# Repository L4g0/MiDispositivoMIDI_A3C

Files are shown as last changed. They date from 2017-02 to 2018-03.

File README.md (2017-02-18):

# BanaNut Electronics
Hi! We are BanaNut Electronics and we develop software and hardware for Arduino with educational purposes. Feel free to visit us in out social networks:
* Instagram: https://www.instagram.com/bananutelectronics
* Twitter: https://twitter.com/bn_electronics
* Facebook: https://www.facebook.com/bananutelectronics
* Tindie: https://www.tindie.com

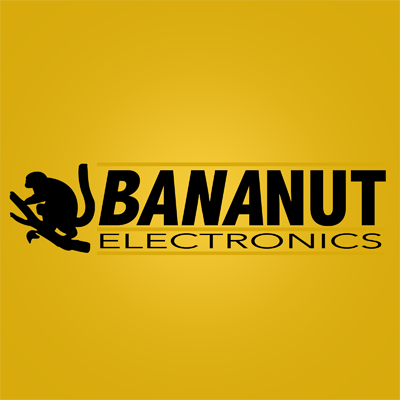
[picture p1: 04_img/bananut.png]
BN_PIC


# MiDispositivoMIDI_A3C
We are proud to present the MiDispositivoMIDI revA3C ([what is that?](https://github.com/bananutelectronics/MiDispositivoMIDI_A3C/wiki), which is the latest version we have out in the market. You can buy it in our webpage or in tindie. In this repository you will find documentation about the controller and code. If you know how to code and you want to colaborate with the project, feel free to do it. If you don't, here you will find a bunch of codes that you just will need to upload to your controller, simple as that.
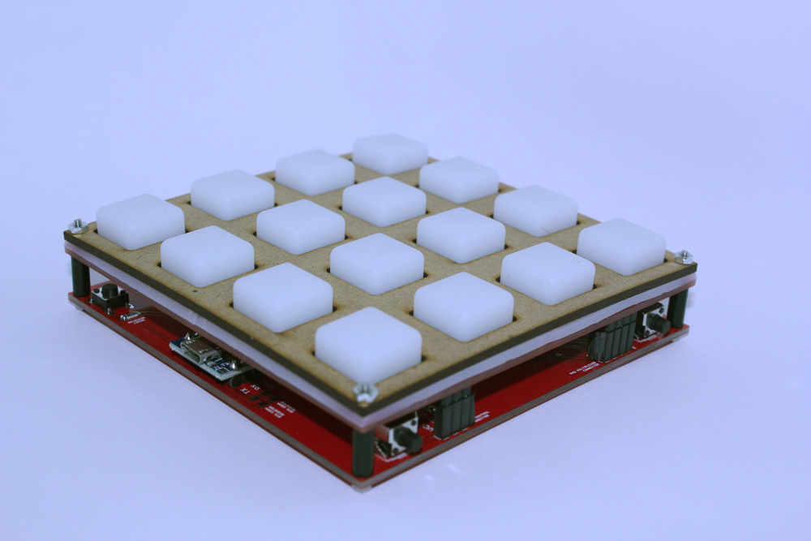
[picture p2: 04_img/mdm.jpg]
MDM_V3_1

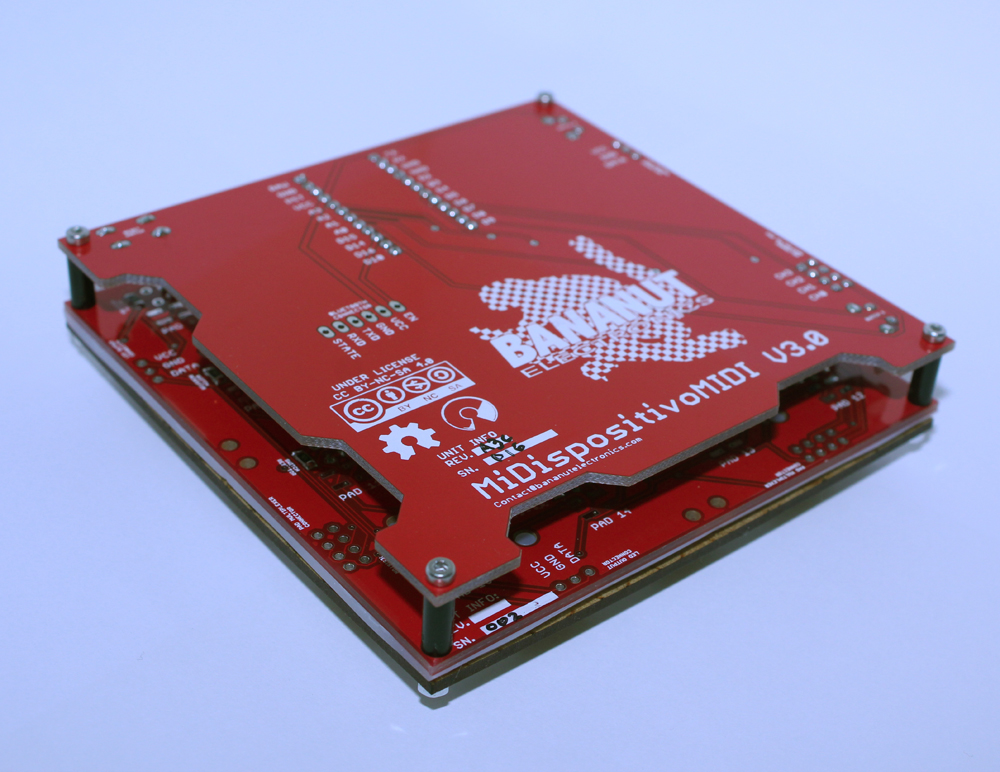
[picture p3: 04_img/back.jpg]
MDM_V3_2


# Important
You will need the following libraries to make the code work: MIDI USB and Adafruit NeoPixel
* https://github.com/arduino-libraries/MIDIUSB
* https://github.com/adafruit/Adafruit_NeoPixel

We also recommend using the Arduino Sketch to make the programming. Remember to select "Arduino Leonardo" as target board.

# Media
* https://www.youtube.com/watch?v=3QnzLwpbpRE&t
* https://www.youtube.com/watch?v=8WFfShg-0Dk
* https://www.youtube.com/watch?v=2y8fhmTmedI
* https://www.youtube.com/watch?v=TsuVpFoLFyI

# General information
* MiDispositivoMIDI is the latest version of our controller.
* It can act as any other MIDI device. There is no need to convert from serial to MIDI.
* Have 16 pad buttons in a 4x4 matrix.
* Have 2 lateral buttons.
* Have RGB leds with 256 levels of intensity of each color.
* Micro USB conection.
* Dimensions of 10x10 cm.

# Documentation
Check the wiki section for further information.

# Hardware License
<br /><span xmlns:dct="http://purl.org/dc/terms/" property="dct:title">MiDispositivoMIDI</span> by <a xmlns:cc="http://creativecommons.org/ns#" href="www.bananutelectronics.com" property="cc:attributionName" rel="cc:attributionURL">Alvaro Lopez & Pablo de Miguel Morales</a> is licensed under a <a rel="license" href="http://creativecommons.org/licenses/by-nc-sa/4.0/">Creative Commons Attribution-NonCommercial-ShareAlike 4.0 International License</a>.<br />

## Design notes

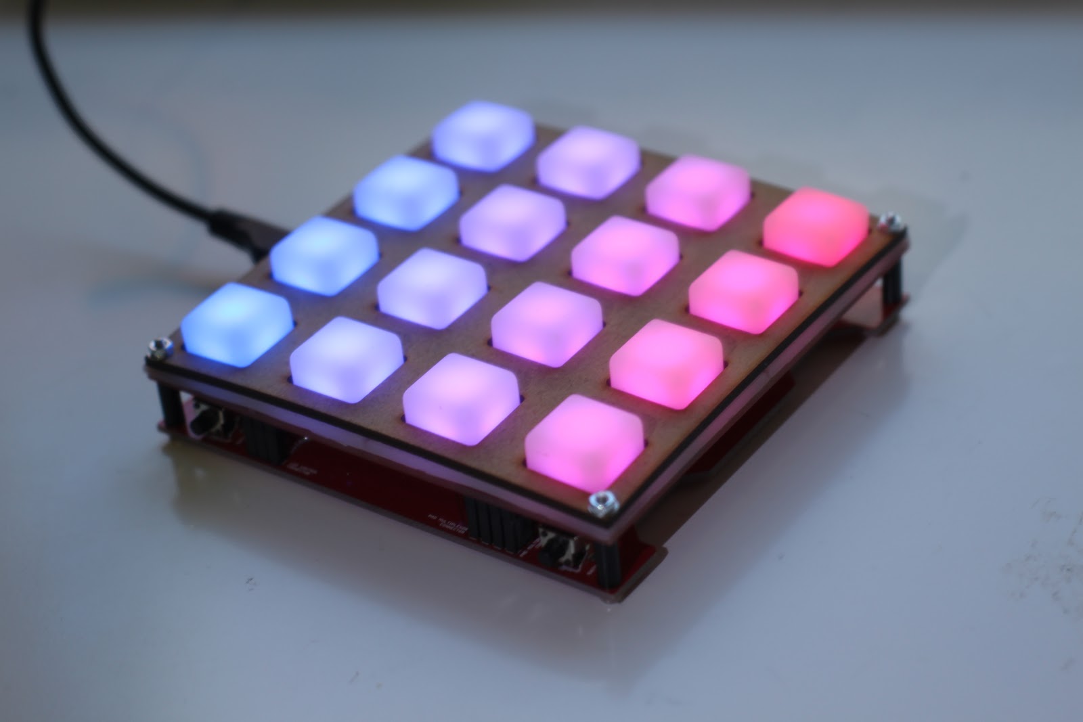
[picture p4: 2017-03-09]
04_img/MDM_V3_INTRO_Device0.JPG

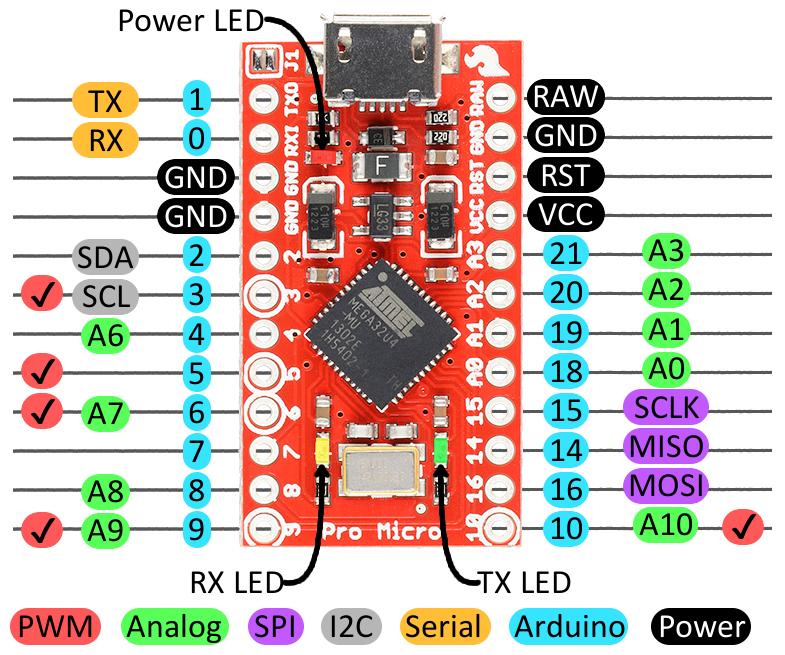
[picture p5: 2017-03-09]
04_img/MDM_V3_HW_ArduinoPinOut.png

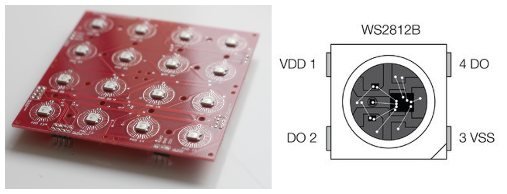
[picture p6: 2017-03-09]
04_img/MDM_V3_HW_WS2812B.PNG

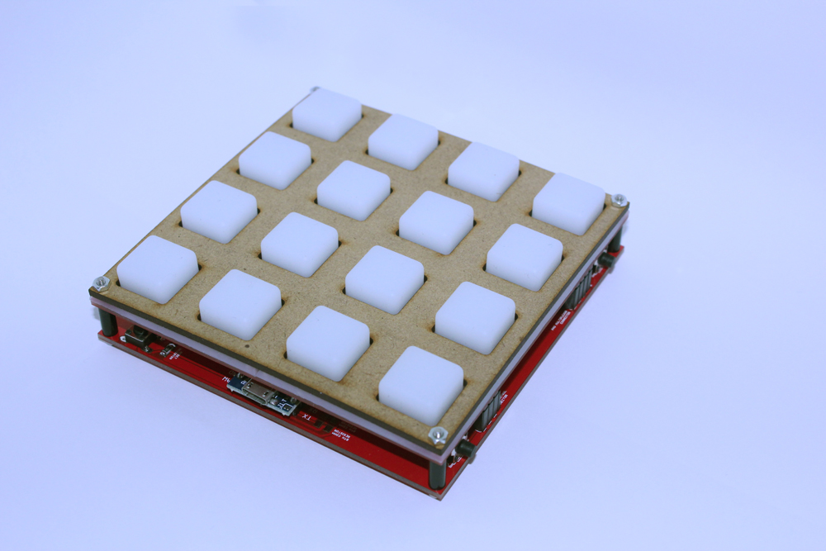
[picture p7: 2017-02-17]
04_img/top.jpg

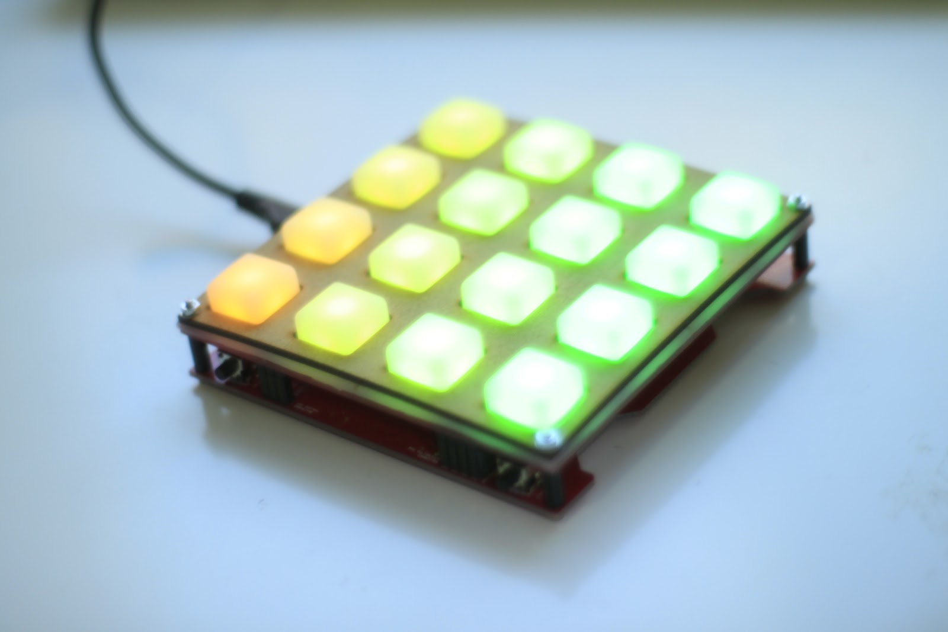
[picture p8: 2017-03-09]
04_img/MDM_V3_INTRO_Device1.JPG

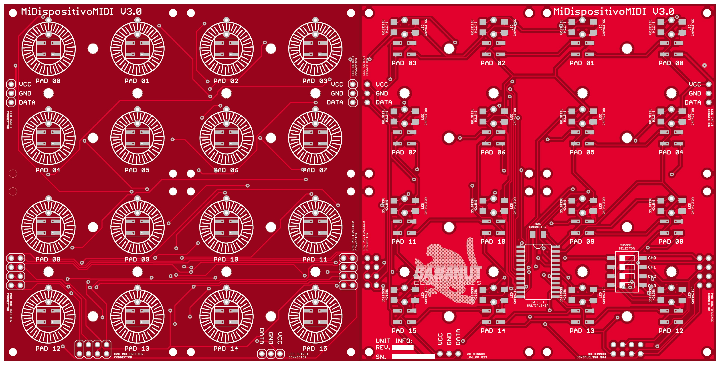
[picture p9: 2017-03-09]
04_img/MDM_V3_HW_LEDPAD_Layer.PNG

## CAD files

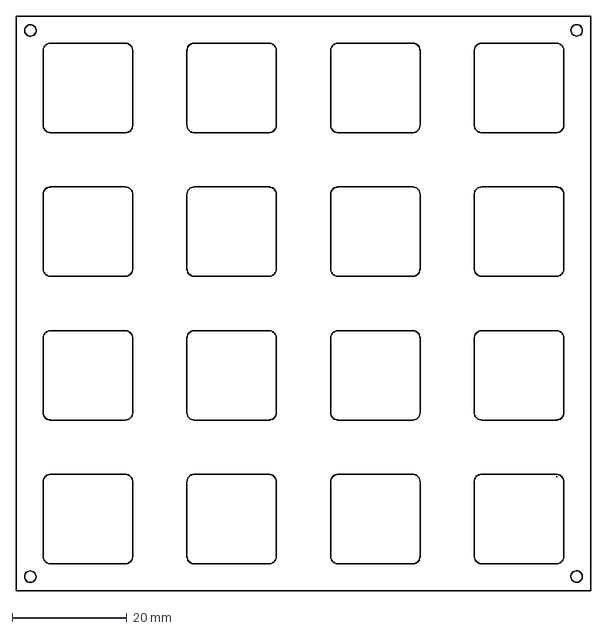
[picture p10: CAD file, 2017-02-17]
02_hw/MDM_V3_Cover.dxf
100.0 x 100.0 mm

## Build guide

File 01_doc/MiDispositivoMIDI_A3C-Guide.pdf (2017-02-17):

Tabla de Contenido
1. Introducción
1.1. ¿Que es MiDispositivoMIDI?
1.2. ¿Que es este documento?
1.3. Desarrollo
2. Protocolo MIDI
2.1 Introducción
2.2 Tipos de mensajes
3. Hardware
3.1. Elementos
3.2. Niveles PCB
3.2.1. MDM_ControlBoard
3.2.2. MDM_LEDPad
3.3. Elementos
3.3.1. LED RGB WS2812B
3.3.2. Multiplexor 74HC4067
3.3.3. Arduino Leonardo Micro Pro
4. Software
4.1 Introducción a la programación 4.1.1 Código
4.1.2 Lenguajes de programación 4.1.3 Entornos de desarrollo 4.1.4 Estructuras de control
4.2 Instalación IDE Arduino
4.3 Funcionamiento IDE Arduino
4.3.1 Fundamentos Arduino
4.3.2 Carga y Compilación de Sketches 4.4 Ejercicios
4.4.1 Ejercicio 1
4.4.2 Ejercicio 2
4.4.3 Ejercicio 3
4.4.4 Ejercicio 4
4.4.5 Ejercicio 5
5. Secuenciadores
5.1 Configuración Ableton
6. Conclusión
6.1 Extensión
6.3 Foro web
6.4 FAQ
7. Inventario de vídeos
8. Inventario código

MiDispositivoMIDI V3.0. User Guide Page 0

# 1. Introducción

## 1.1. ¿Que es MiDispositivoMIDI?

MiDispositivoMIDI es un controlador MIDI Open Source basado en Arduino. Puede ser usado con cualquier programa de audio como Ableton o Logic y dispone de las siguientes características:
- 16 botones tipo PAD ON/OFF, dispuestos en una matriz de 4x4.
- 16 LED RGB, situados debajo de cada botón.
- 2 botones laterales configurables.
- Conexión USB con cable MicroUSB.
- Dimensiones de 10x10 cm.

El controlador viene programado por defecto y se comercializa montado y listo para ser utilizado. También se le pueden cargar los códigos disponibles en nuestro repositorio de GitHub o programar a medida.

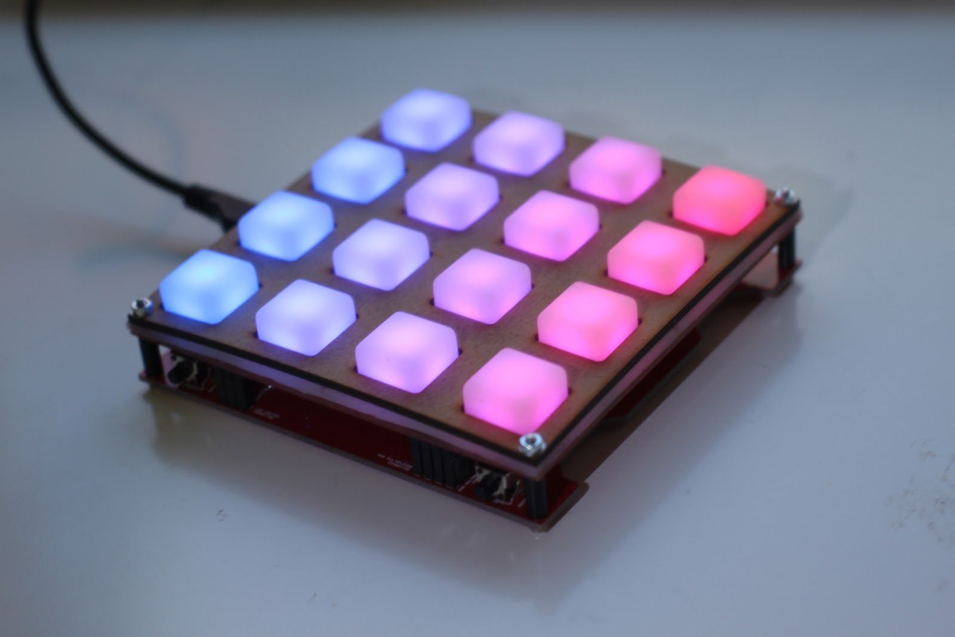
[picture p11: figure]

Figura 1. MiDispositivoMIDI en funcionamiento (1/2).

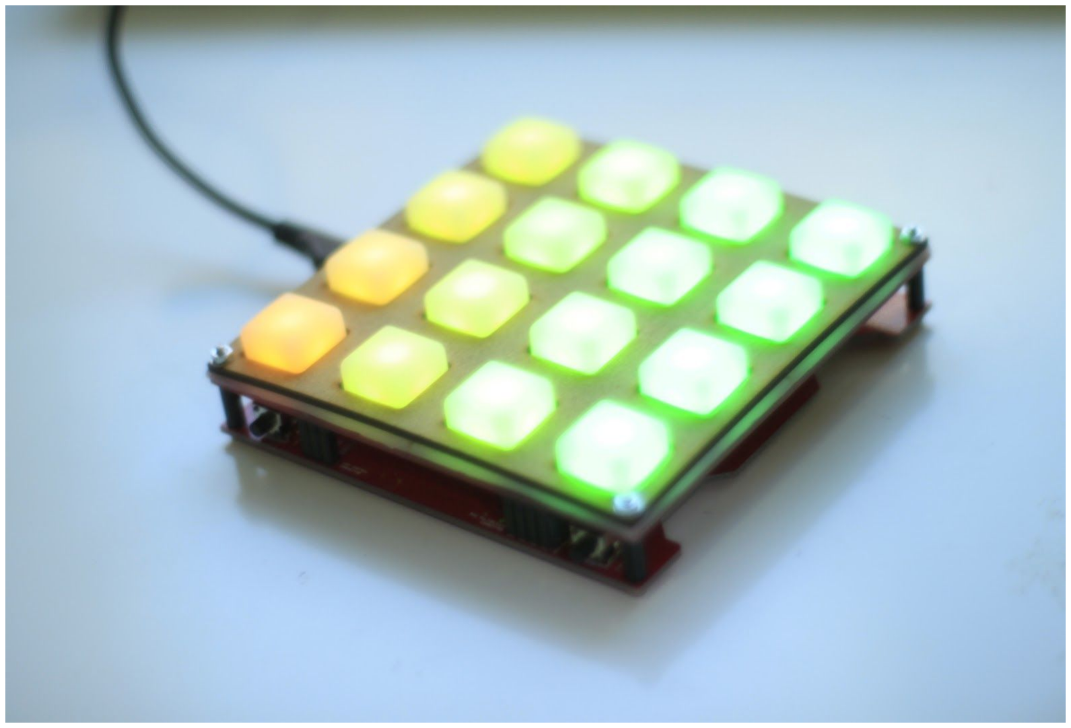
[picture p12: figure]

Figura 2. MiDispositivoMIDI en funcionamiento (2/2).

## 1.2. ¿Que es este documento?

Esta guía pretende orientar a los usuarios del controlador MiDispositivoMIDI Rev A3C. Se cubren aspectos desde lo más general (uso, configuración, componentes,...) hasta lo más avanzado (programación, esquemáticos, circuitos). Además del presente documento, se recomienda consultar:
- Vídeos de youtube: En estos vídeos se explican ciertos apartados de la guía, de manera más visual. Enlace. (https://www.youtube.com/channel/UCHQbpOPa1lVauoBouRJ16Iw)
- Repositorio: En dicho repositorio (https://github.com/bananutelectronics/MiDispositivoMIDI_A3C) de GitHub se pueden encontrar diversos códigos que puedes cargar en el controlador, sin tener conocimientos de ningún tipo. Para cargar códigos, ver el vídeo “Instalación”. (https://www.youtube.com/channel/UCHQbpOPa1lVauoBouRJ16Iw)

## 1.3. Desarrollo

El controlador MiDispositivoMIDI tiene sus orígenes en la Universidad Politécnica de Madrid (UPM), donde dos alumnos de Ingeniería de Telecomunicación, decidieron empezar con un controlador MIDI basado en Arduino.
Su primera versión, se basaba en Arduino UNO, empleaba registros de desplazamiento para la iluminación de los LEDs y enviaba mensajes empleando el puerto serial. De dicha versión se hicieron 40 unidades, y se impartió el primer curso, allá por el año 2013.
Tras varias mejoras y cambios de firmware en el Arduino, se llegó a la versión 2.0 del controlador. Las carcasas eran de madera, y la comunicación con el ordenador ya se establecía a través de MIDI. Se hicieron también 40 unidades, y se impartió un curso con muy buena acogida.

Tras un tiempo parados, pero habiendo escuchado todas las mejoras propuestas por nuestros compañeros, decidimos lanzar la tercera versión de MiDispositivoMIDI. Se trata de un controlador mucho más fino, más ligero, con un Arduino más potente, LEDs que permiten generar miles de colores y fácilmente ampliable. Hemos fabricado una tirada grande de esta tercera versión, y ¡estamos deseando dártela!

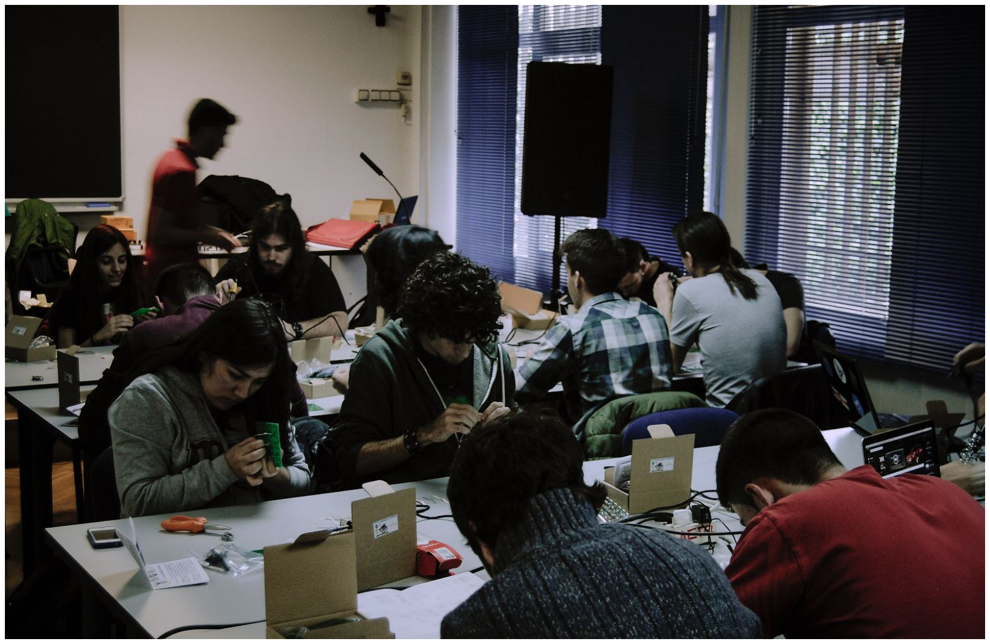
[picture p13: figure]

Figura 3. Asistentes de la primera edición de MiDispositivoMIDI.

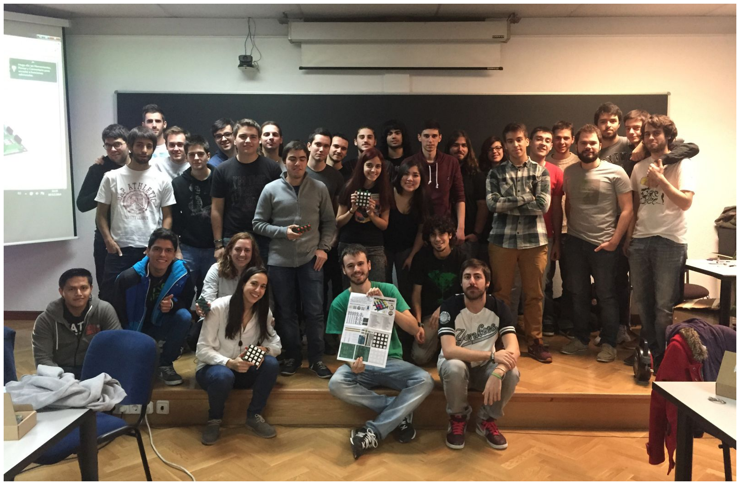
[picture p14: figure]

Figura 4. Asistentes de la segunda edición de MiDispositivoMIDI.

# 2. Protocolo MIDI

## 2.1 Introducción

El protocolo MIDI (Musical Instruments Digital Interface) es un lenguaje que utilizan actualmente muchos instrumentos musicales para comunicarse entre ellos y con un ordenador. Su uso les permite enviar y recibir mensaje además de sincronizarse. Se trata de un protocolo con mucha historia, y data de la década de los 80s. Aún así, se sigue usando hoy en día en gran cantidad de teclados, controladores, cajas de ritmo e incluso para controlar luces.

Por ejemplo, el teclado que mostramos a continuación se puede conectar al ordenador con un cable USB y cuando pulsemos una tecla, enviará un mensaje MIDI al ordenador a través del cable. Evidentemente no va a ser el mismo mensaje si pulsamos la tecla muy fuerte o suave, o si pulsamos una tecla u otra. A continuación lo explicaremos.

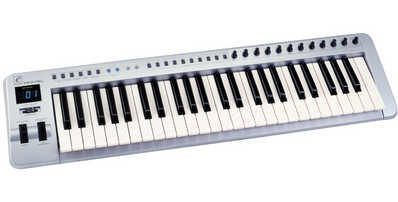
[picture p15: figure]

Figura 5. Ejemplo de controlador MIDI. Teclado controlador.

## 2.2 Tipos de mensajes

Antes de nada vamos a recordar que es un bit y un byte. Un bit es la unidad mínima de información digital, es decir un 0 o un 1. Un byte es un conjunto de 8 bits. Cada mensaje MIDI tiene 3 bytes, es decir 24 bits. En función del valor que tenga, el mensaje significará una cosa u otra. A continuación mostramos los 3 paquetes de 1 byte que contiene cada mensaje MIDI. El primero corresponde al byte de estado, y lleva la información relativa al estado y el canal. El estado hace referencia al tipo de mensaje: nota activada, nota desactivada, bend, cambio de programa u otros más. El canal puede tomar valores de 0 a 15, y permite separar diferentes flujos de mensajes.

BYTE 1 (Status Byte)

Estado | Canal
X | X | X | X | X | X | X | X
El segundo y tercer byte, llevan información que variará en función del estado. Para el caso de un estado noteOn, el BYTE 2 indicará la nota y el BYTE 3 indicará la intensidad de la nota.
BYTE 2 (Data Byte 1)
X | X | X | X | X | X | X | X

BYTE 3 (Data Byte 2)

X | X | X | X | X | X | X | X

Particularizando para el ejemplo de un mensaje de nota activada noteOn, vamos a ver los bits que se enviarán para un caso concreto.

Ejemplo noteOn

Nota | DO
Octava | 3
Intensidad | Máxima
Canal | 0

Por un lado, la tercera octava de DO se corresponde con el valor MIDI 48. La intensidad máxima se corresponde con el valor 127, ya que en MIDI las intensidades varían desde 0 a 127, siendo 0 la menor. Sabiendo que 48 en binario es 0110000, 127 es 1111111, el código de noteOn es 1001 y 0 en binario es 0000, tenemos lo siguiente:

noteOn | Canal | | Nota | | Intensidad
1 | 0 | 0 | 1 | 0 | 0 | 0 | 0 | 0 | 0 | 1 | 1 | 0 | 0 | 0 | 0 | 0 | 1 | 1 | 1 | 1 | 1 | 1 | 1

Como podemos ver, el bit 9 y el 17 se indican en color rojo. Esto es debido a que estos bits van a ir siempre a 0, sin importar el mensaje enviado. Para otros mensajes, la estructura es similar.

EJERCICIO PROPUESTO (INDICADOR NÚMERO)

Se propone escribir el mensaje MIDI completo en binario que se enviaría al pulsar la nota

LA de la tercera octava, con una intensidad de 90.

# 3. Hardware

## 3.1. Elementos

MiDispositivoMIDI V3 está conformado por diversos elementos que componen tanto su estructura mecánica como su estructura electrónica. En las siguientes secciones se recogen y analizan distintos aspectos del circuito para que sean comprendidos tanto por iniciados como por usuarios más avanzados de la electrónica.

Los elementos que componen MiDispositivoMIDI V3 son:

QUANTITY. | ITEM

01 Silicone Pad 4x4 10x10cm

01 Wooden CNC Laser Cut MiDispositivoMIDI V3 Cover

01 PCB MDM_V3_ControlBoard

01 PCB MDM_V3_LedPad

01 Arduino Leonardo Micro Pro

16 WS2812B RGB Addressable LED

18 Ceramic Capacitor SMD 1206 10uF

19 Resistor SMD 1206 10kOhm

01 Resistor SMD 1206 47Ohm

02 Angled Tactile Switch

01 Tactile Switch

01 IC 74HC4067 16to1 Multiplexer

01 DIP Switch 1x4 SMD

01 Male 2x4 Pin Row

01 Male 1x3 Pin Row

01 Female 2x4 Pin Row

01 Female 1x3 Pin Row

04 M2x20 Screw

04 M2 Black Plastic Screw Separator

04 M2 Washer

04 M2 Nut

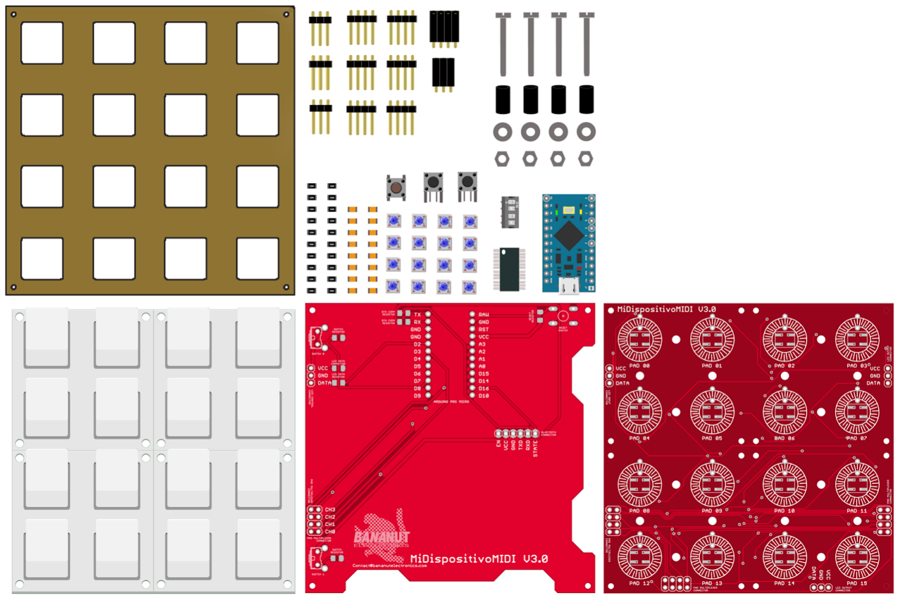
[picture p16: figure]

Figura 6. Componentes de MiDispositivoMIDI.

## 3.2. Niveles PCB

MiDispositivoMIDI V3 está conformado por 2 distintas PCBs. Una PCB (Printed Circuit Board) es una lámina de fibra con pistas conductoras metálicas sobre las que se sueldan los componentes de cualquier producto electrónico. Las PCBs se pueden encontrar en todos los dispositivos independientemente de su complejidad y función.

MiDispositivoMIDI hace uso de dos PCB conectadas a través de pines (sin cables) de modo que se trata de una conexión muy robusta.

### 3.2.1. MDM_ControlBoard

La placa de control (MDM_ControlBoard) contiene la unidad principal de procesado del dispositivo con el microcontrolador Arduino Leonardo así como los dos botones de control (Switch 0 y Switch 1) y un botón de Reset (Reset Switch). Dispone también de un pad en el que se puede soldar un módulo Bluetooth. Esta funcionalidad, sin embargo, no ha sido todavía implementada pero se anima a todo aquel que quiera intentarlo a experimentar con un MiDispositivoMIDI inalámbrico.

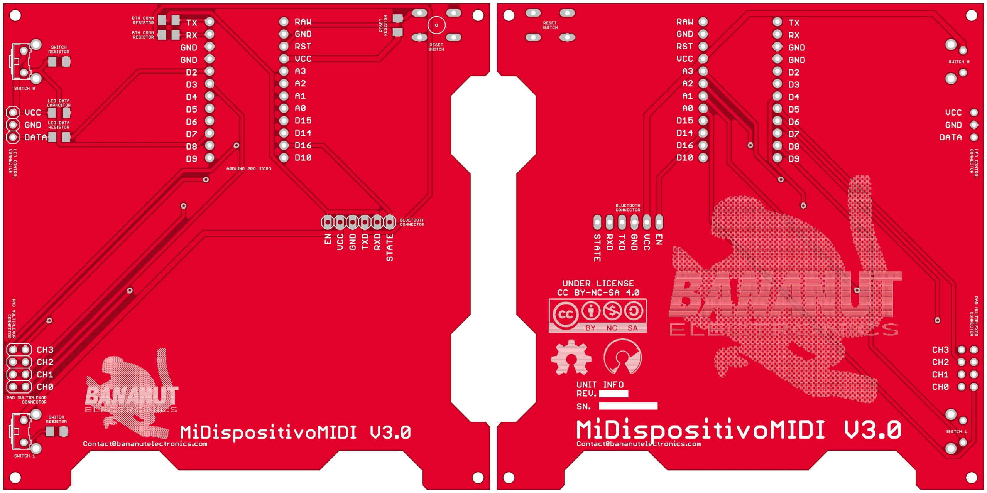
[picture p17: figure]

Figura 7. PCB inferior de MiDispositivoMIDI. A la izquierda se muestra la capa superior, a la derecha la inferior.

### 3.2.2. MDM_LEDPad

La placa del Pad Led 4x4 (MDM_LEDPad) conforma junto con el Pad de silicona la parte principal del dispositivo. Consiste en un Pad formado por 16 LEDs WS2812B dispuestos en una fila. El funcionamiento de estos LEDs se describe más adelante en este documento. Cuenta además con resistencias para los switchs y un multiplexor 74HC4067 que permite el control de todos los pads a través de solo 5 pines.
Una peculiaridad atractiva de MiDispositivoMIDI es la posibilidad de conectar hasta cuatro MDM_LEDPad con un solo MDM_ControlBoard. Esto abre la posibilidad a montar un MiDispositivoMIDI de 8x8 o 4x16 Pads.

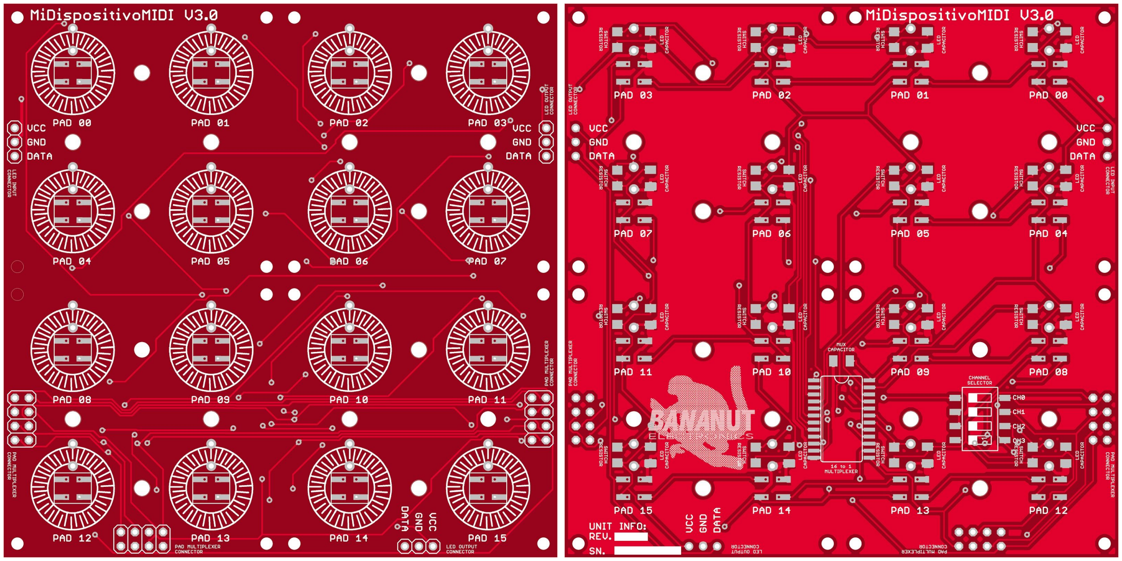
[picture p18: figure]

Figura 8. PCB superior de MiDispositivoMIDI. A la izquierda se muestra la capa superior, a la derecha la inferior.

Debido a la robustez de las PCBs, se han usado también para conformar la parte mecánica del dispositivo.

## 3.3. Elementos

Es esta sección se analiza el funcionamiento de distintos elementos relevantes de MiDispositivoMIDI V3.

### 3.3.1. LED RGB WS2812B

Los LED WS2812B popularizados por Sparkfun son una maravilla de la técnica que simplifica mucho el uso de LEDs RGB gracias a la posibilidad de controlarlos y organizarlos en tiras que pueden ser controladas tan solo a través de un pin (una sola línea de datos).

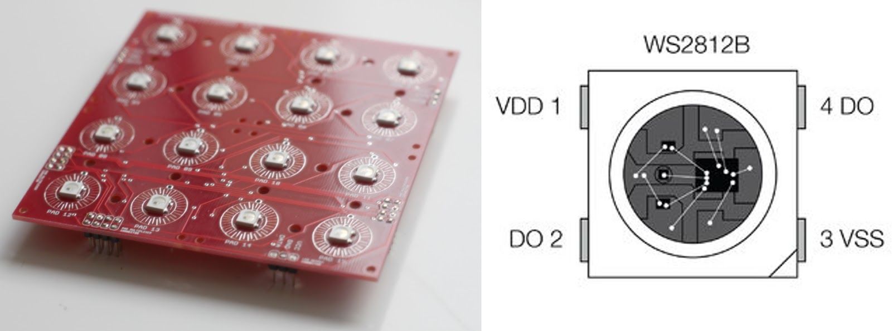
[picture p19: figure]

Figura 9. A la izquierda la PCB superior con sus LEDs. A la derecha el esquemático de un LED.

Su funcionamiento se basa en la integración en un solo integrado de 3 LEDs (RGB), una etapa de alimentación y un registro serie. De este modo, tan solo alimentando la tira entera con 5V, se puede definir el color de cualquiera de los LEDs de manera individual con una precisión de 3x8bit, es decir, se pueden logar un total de más de 16 millones de colores distintos.
Su control a través de Arduino se hace a través de la librería Adafruit_Neopixel, que a través de funciones ofrece una interfaz simplificada para trabajar con estos ICs.

### 3.3.2. Multiplexor 74HC4067

Un multiplexor es un circuito integrado (IC) que dispone de 2 puertos de entrada, un puerto

X
de salida y X puertos de selección. Su funcionamiento consiste en ofrecer a su salida el valor existente en el puerto de entrada seleccionado a través de los puertos de selección, tal y como se recoge en esta tabla genérica para un multiplexor 4to1:
ENA | SEL[1:0] | SEL[DEC] | OUTPUT
0 | XX | X | GND
1 | 00 | 0 | INPUT_0
1 | 01 | 1 | INPUT_1
1 | 10 | 2 | INPUT_2
1 | 11 | 3 | INPUT_3

El Multiplexor 74HC4067 es un multiplexor de 16 canales, con lo cual a través de solo 5 pines (4 de selección y 1 de salida) se pueden controlar los 16 botones de cada Pad. La lectura se hace de forma secuencial, es decir, se establece un valor de SEL[3:0] y se lee la señal a la salida. Se lee por lo tanto solo el valor de uno de los Pads a cada momento, pero dado que la lectura de cada pad tiene una duración aproximada de 5ms, la sensación de uso es similar a que todos los Pads fuesen leídos simultáneamente en todo momento.

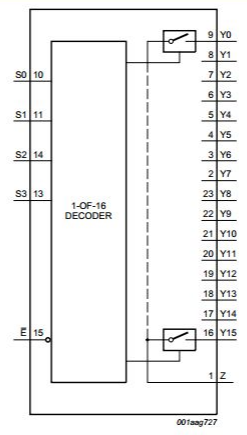
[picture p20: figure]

Figura 10. Esquemático de un multiplexor.

En código, está secuenciación y uso del multiplexor se modelan de la siguiente forma:

/* Function void readPADs()
* Reads the PADs through the MUX.
* Reads a number of LEDPAD_EXT Channels starting from 0 */
void readPADs(){
for(int i=0; i<LEDPAD_NUM; i++){ // PAD Button Iterator for(int h=0; h<4; h++){
digitalWrite(muxPin[h], ((i>>(3-h)) & 0x01)); //MUX SetUp }
delay(5); // Time por MUX SetUp
for(int j=0; j<LEDPAD_EXT; j++){ // PAD Channel Iterator padRead[j][i] = analogRead(padPin[j]); //Assign Reads to PAD matrix }
}
}

En el código se escribe en cada pin de muxPin[3:0] el valor correspondiente en notación binaria de un número entre 0 y 15 (Que abarca los 16 Pads de la botonera).

### 3.3.3. Arduino Leonardo Micro Pro

El Arduino Leonardo Micro Pro es un modelo de Arduino de potencia reducida pero con un microprocesador ATMEGA3204 que reúne una serie de características muy interesantes para la aplicación de MiDispositivoMIDI:
- Conector microUSB.
- Capacidad de funcionar como HID (Human Interface Device) sin necesidad de cambiar el firmware. Puede ser reconocido por el ordenador como un controlador MIDI comercial, sin necesidad de realizar configuraciones.
- Tamaño reducido

Existen también otras versiones de Arduino, como el Arduino UNO o el Arduino MEGA2504. Cada modelo de Arduino cuenta con una serie de características ligeramente distintas de otras (tamaño, potencia, periféricos especiales, Bluetooth) por lo que antes de desarrollar cualquier sistema es necesario informarse de cuál es el objetivo del proyecto y cuál de los modelos de Arduino encaja mejor con las especificaciones.

Uno de los elementos más diferenciadores de los modelos de Arduino es el pinout. El pinout es la definición de los pines del Arduino, es decir, cual es la capacidad del procesador para comunicarse, leer o manejar periféricos (Elementos externos. Cubre desde motores a LEDs, SDcards, etc).

Arduino tiene definidas distintas categorías de pines, según su funcionalidad. Las funcionalidades principales son:

- Pin 5V: Pin de alimentación de periféricos que entrega una tensión de 5V (Salida del regulador 7805 de la placa) con respecto a GND y una corriente máxima de
- Pin 3.3V: Pin de alimentación de periféricos que entrega una tensión de 3.3V (con respecto a GND y una corriente máxima de
- Pin VIN/RAW:Pin de alimentación de entrega la tensión de alimentación del Arduino (La tensión que el Arduino recibe, por ejemplo la alimentación USB o la entregada por unas baterías)
- Pin GND: Pin de retorno GND común al Arduino (Debe, en principio, ser la referencia de tensión única del sistema).
- Pin Reset: Pin de Reset del atmega328 activo a nivel bajo. Si este pin se conecta a GND, el Arduino se reinicia.
- Pin Digital (DX): Pin para la lectura y generación de señales digitales. Además, pueden tener asociadas otras funcionalidades como comunicación I2C, SPI, o capacidad para generar señales PWM.
- Pin Analógico (AX): Pin para la lectura (No generación) de señales analógicas de 0 a 5V con una precisión de 10b (En la lectura, dará un valor de 1023 para señales de 5V y de 0 para señales de 0V). Son además pines digitales.

En general se debe tener en cuenta en el sistema:

- Nunca cortocircuitar las señales de GND, VIN, 5V y 3.3V ya que provocaría el reinicio y degradación del Arduino llegando en la mayoría de los casos a romperlo.
- Utilizar el pin de 5V para alimentar periféricos de bajo consumo (LEDs, potenciómetros, sensores, etc) y una alimentación externa para alimentar actuadores de alto consumo (motores, servomotores, etc).
- Dejar el pin de Reset desconectado o conectado a nivel alto (5V) a través de un pull-up.

A continuación se muestra gráficamente el pinout del Arduino Leonardo Micro que usa MiDispositivoMIDI V3:

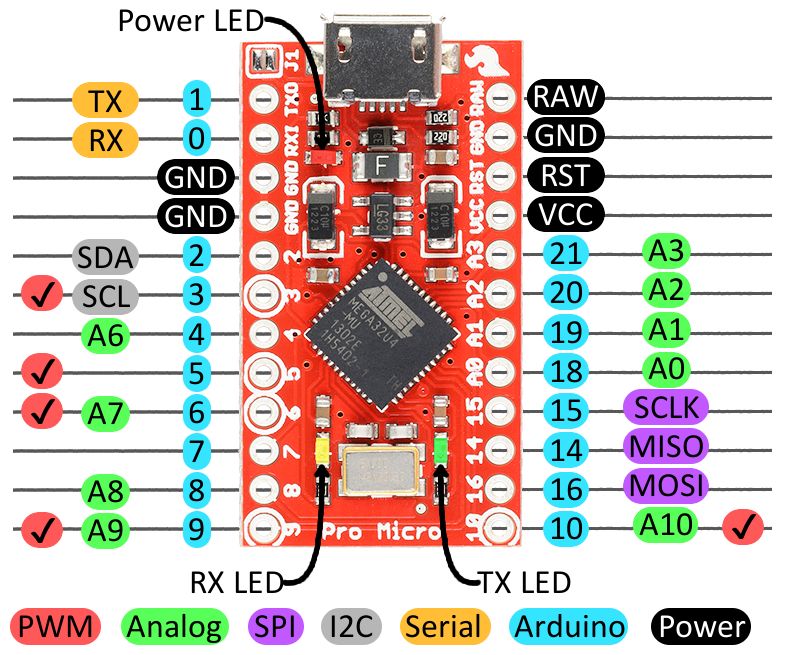
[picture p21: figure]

Figura 11. Diagrama de pines del Arduino Pro Micro (Leonardo).

Se puede observar como dispone de hasta 11 pines Analogicos [A0:A10], así como de 3 pines de GND (Que son la mismas señal pero se duplican para tener conexiones más cómodas) así como pines dedicados a SPI (14,15,26), I2C (SDA, SCL) o comunicación Serial (TX, RX).
En el caso de MiDispositivoMIDI, se hace uso de los pines exclusivamente como pines de tipo digital (Para controlar tanto los LEDs como el multiplexor o la lectura de los Switches) como de tipo analógico (Para la lectura del valor de los Pads a la salida del multiplexor). Los pines 0(RX) y 1(TX), se usan para a comunicación Serial (por USB) de modo que no se deben conectar a ningún otro punto.

# 4. Software

## 4.1 Introducción a la programación

A continuación se explican algunos conceptos importantes de la programación, que serán de ayuda en el caso de que quieras programar MiDispositivoMIDI. Se pretende sólo dar unas nociones.

### 4.1.1 Código

Un código es un texto, que contiene un conjunto de instrucciones que pueden ser ejecutadas en un ordenador. En nuestro caso el ordenador será el controlador. Se observa a continuación un código de ejemplo.

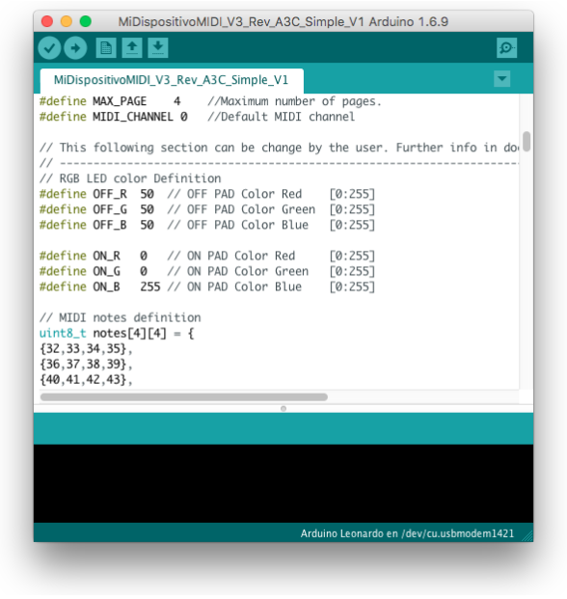
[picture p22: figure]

Figura 12. Ejemplo de un código en el IDE de Arduino.

Cuando se escribe un código y se quiere cargar en un ordenador o microcontrolador para que pueda ser ejecutado, se requiere de un compilador. Las principales tareas que realiza el compilador son: verificar que no hay errores de sintaxis y generar un código entendible por la máquina en ceros y unos. Más adelante se explica cómo pasar de un código (texto) a algo entendible por el Arduino (código máquina).

### 4.1.2 Lenguajes de programación

Existen diversos lenguajes de programación, cada uno con sus ventajas e inconvenientes. Java, C, C++ o Python son algunos de los lenguajes de programación más conocidos y usados. A pesar de que tienen sus diferencias, resultan todos muy similares. El controlador MiDispositivoMIDI está pensado para ser programado en C.

### 4.1.3 Entornos de desarrollo

Un entorno de desarrollo es un programa que hace más fácil escribir código. Por ejemplo, permite detectar y corregir errores según se va escribiendo. Es decir, es algo así como el Word pero en la programación, ya que hace mucho más fácil escribir código.
Los entornos de desarrollo también tienen un compilador, que permite pasar de código en texto a algo entendible por el Arduino.

Arduino tiene su propio entorno de desarrollo, llamado Arduino IDE. Es la herramienta que permite compilar y cargar códigos al Arduino de vuestro controlador. Más adelante se explicará cómo descargarlo e instalarlo.

### 4.1.4 Estructuras de control

En programación estructurada, que es al grupo al que pertenece C, el código se ejecuta de manera secuencial. Esto significa que se va ejecutando desde el principio hasta el final, línea por línea. Cada línea o conjunto de líneas son una instrucción, como puede ser encender un LED o enviar una nota MIDI.
Dado que muchas veces no solo basta con ejecutar de principio a final, en la programación existen las estructuras de control, que son sentencias que permiten modificar el flujo de ejecución del programa en función de determinadas variables. Se explican las fundamentales: if, while y for.

El código if, permite ejecutar una sección de código si se cumple una determinada condición. Se muestra un ejemplo:

IF (variable < 30){
EJECUTA ACCIÓN
}

Significa que si una determinada variable llamada variable es menor que 30, se ejecuta la acción encerrada entre llaves {}. Es habitual en lenguajes como C, el uso de las llaves como se indica. La variable podría ser una temperatura y la acción encender una calefacción. Es decir, si la temperatura es menor que 30, ejecutar la acción de encender la calefacción.

En el caso del while, se trata de una estructura de control en forma de bucle. Ejecuta la acción mientras se cumpla una determinada condición.

WHILE (variable < 30){
EJECUTA ACCIÓN.
}

En el ejemplo mostrado, se ejecutaría la acción mientras la variable tenga un valor menor que 30. En el momento en el que la variable supere ese valor, se deja de ejecutar el bucle. La diferencia entre el while y el for es que el while se repite siempre que se cumpla la condición, mientras que el if solamente se ejecuta una vez.

Por último, el for se puede pensar como una especie de while, con la salvedad que se sabe el número de veces que se va a ejecutar la acción. El número de veces se especifica en el código.

for (i=0; i<5; i++){

EJECUTA ACCIÓN;
}

Para los for se usa una variable auxiliar, la i. Se inicializa i=0 y mientras la i sea menor que 5 se ejecuta la acción que está dentro del for. En cada iteración se aumenta la i en una unidad, eso es lo que significa “i++”. Por lo tanto, el ejemplo anterior se ejecutará la acción entre llaves 5 veces.

## 4.2 Instalación IDE Arduino

El IDE de Arduino es un entorno de desarrollo muy sencillo pensado para escribir código y cargarlo al Arduino. El objetivo de esta sección es enseñar cómo usarlo, para que podáis cargar los códigos que os demos, simplemente abrir el código y cargarlo (ver repositorio de código). A las personas con más conocimientos de programación, las invitamos a que creen sus propios códigos y los compartan.

Para descargarlo, basta con acceder al siguiente enlace y seleccionar vuestro sistema operativo. Se da la opción de donar a la causa, pero si no queréis, hacer click en “Just Download”

https://www.arduino.cc/en/Main/Software

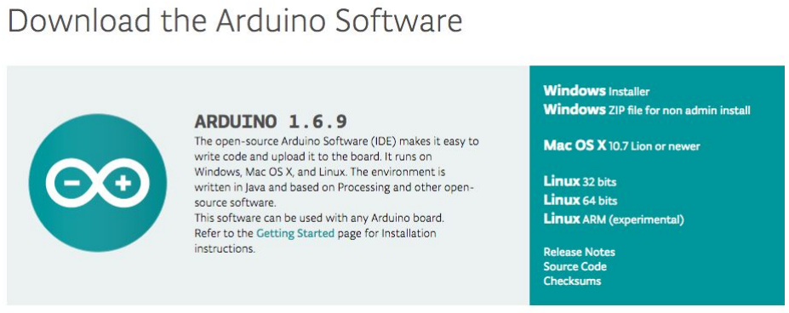
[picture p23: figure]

Figura 12. Web de Arduino

El siguiente paso es descargar dos librerías necesarias: una librería MIDI, y una librería para el control de los LEDs desarrollada por Adafruit. Los enlaces son los siguientes.

https://github.com/arduino-libraries/MIDIUSB

https://github.com/adafruit/Adafruit_NeoPixel

Para descargar cada librería, seleccionar “Clone or download” y despues “Download ZIP”.

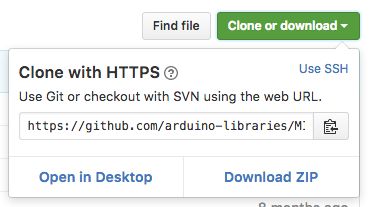
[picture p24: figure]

Figura 13. Descarga de una librería en GitHub.

Una vez descargadas las dos librería el el IDE de Arduino, abrir el programa de Arduino. En Mac puede dar problemas si os dice que proviene de un desarrollador no identificado. Darle permiso en preferencias.

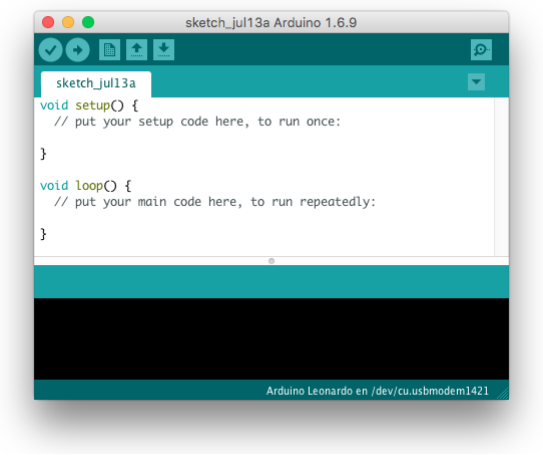
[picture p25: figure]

Figura 14. Ejemplo del código básico de Arduino.

Ahora solo falta decirle al programa donde tiene que localizar las librerías necesarias. Para ello, “Programa”/”Incluir librería”/”Incluir librería ZIP”.

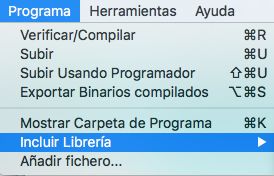
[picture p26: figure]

Figura 15. Menú para incluir una librería en Arduino.

Una vez seleccionadas las dos, ya estáis en condiciones de cargar cualquier código que os proporcionemos. Diferentes códigos realizarán diferentes funciones, por lo que os aconsejamos leer la documentación de cada código antes de cargarlo, para saber qué hace.

Los códigos de Arduino tienen la extensión “*.ino” y se encuentran almacenados en una carpeta con el mismo nombre que código.

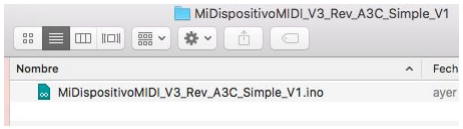
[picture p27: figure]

Figura 16. Forma de almacenamiento de un código en Arduino.

## 4.3 Funcionamiento IDE Arduino

### 4.3.1 Fundamentos Arduino

El lenguaje de programación de Arduino es C con ciertas particularidades. Un código de Arduino debe tener siempre dos zonas diferenciadas: setup y loop.

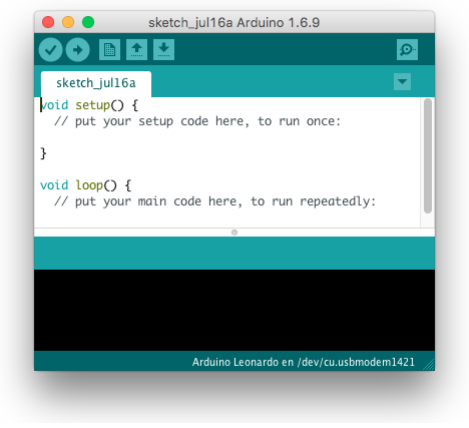
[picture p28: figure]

Figura 17. Estructura del código de Arduino.

En el setup se realiza la configuración del Arduino. Por ejemplo, se dice que pines son de entrada y cuales son de salida. Por otro lado el loop es el código que se estará ejecutando continuamente. Recordad que como se explicó antes, en la programación el código se ejecuta línea por línea, por lo que si no existiera un loop que estuviera continuamente ejecutándose, llegaría un momento en el que se habría ejecutado todo y el Arduino ya no realizaría nada.

### 4.3.2 Carga y Compilación de Sketches

Antes de cargar un código de Arduino, es necesario verificar que se tiene seleccionada la placa correspondiente. Esto es debido a que existen diferentes modelos de Arduino, y un código se compila para un modelo determinado. En el caso de MiDispositivoMIDI es necesario seleccionar “Arduino Leonardo”.

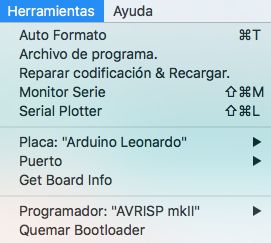
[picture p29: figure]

Figura 18. Configuración del puerto de comunicación con Arduino.

También es necesario seleccionar el puerto al que está conectado Arduino. Si usamos Arduino conectado por USB, que es el caso, es necesario seleccionar el siguiente puerto. Es posible que en Windows aparezca otro nombre.

Figura 19. Puerto USB configurado en MAC.

## 4.4 Ejercicios

A continuación se explican paso a paso varios ejercicios, que tienen como fin guiar al usuario en los fundamentos de la programación de MiDispositivoMIDI. Van desde el manejo de los LEDs hasta el envío de mensajes MIDI.

### 4.4.1 Ejercicio 1

Si abrimos el código “MiDispositivoMIDI_V3_Rev_A3C_Exercise1.ino”, nos encontraremos con un primer ejemplo que nos permitirá saber cómo se programan los LEDs, para saber
cual | encendemos y de qué color.
Código | MiDispositivoMIDI_V3_Rev_A3C_Exercise1.ino
Descripción | Entender el funcionamiento de los LEDs, para poder encender un determinado LED del color que queramos. Se consideran 16 LEDs (4x4) y 3 posibles colores (rojo, verde y azul) con diferentes intensidades configurables
Objetivos | Saber iluminar el LED que queramos en un determinado color. Entender que cada color tiene 256 intensidades posibles. Ver de forma práctica la formación de un color a través de sus componentes rojo, verde y azul (RGB de aquí en adelante).
Ejercicios | 1. Modificar los colores, tanto puros (RGB) o mezcla de varios. 2. Iluminar varios LEDs a la vez.

Como se puede ver en la siguiente sección de código, la matriz “ledPad” es la responsable de almacenar los colores para cada LED. El ejemplo que se muestra ilumina el primer LED, ubicado en el borde superior a la izquierda, de color verde.
ledPad[0][0] = 0; //0 corresponds to the intensity of red color
ledPad[0][1] = 255; //1 corresponds to the intensity of green color
ledPad[0][2] = 0; //2 corresponds to the intensity of blue color
Como podemos ver, “ledPad” es una matriz de dos dimensiones, por lo que hay que especificar dos valores almacenados entre corchetes. El primer valor, siempre a cero en el ejemplo se refiere al LED. Como tenemos 16 LEDs, el valor irá desde 0 a 15. Si queremos encender el segundo LED, tendremos que poner el valor 1. La correspondencia es la siguiente:
0 | 1 | 2 | 3
4 | 5 | 6 | 7
8 | 9 | 10 | 11

12 | 13 | 14 | 15

El segundo elemento de “ledPad”, que en el va desde 0 a 2, indica las componentes de color rojo, verde y azul. La correspondencia es la siguiente:

Color | Código
Rojo | 0
Verde | 1
Azul | 2

Y el valor que se asigna a cada elemento de “ledPad”, es la intensidad de cada color desde 0 a 255. Por lo tanto, si quisiéramos un color azul en el primero botón (referido como 0), el código sería el siguiente:

ledPad[0][0] = 0; | //0 corresponds to the intensity of red color
ledPad[0][1] = 0; | //1 corresponds to the intensity of green color
ledPad[0][2] = 255; //2 corresponds to the intensity of blue color

Si usáramos un valor de 200 en vez de 255, el color sería también azul pero de menor intensidad. Se trataría de un azul claro.

Recordar que después de hacer modificaciones en la matriz “ledPad”, es necesario llamar a la función updateLEDs(). Esta función simplemente lleva el contenido que hayamos introducido en la matriz al controlador.

### 4.4.2 Ejercicio 2

En el apartado anterior hemos visto cómo iluminar un determinado LED del color que queramos. A continuación vamos a crear animaciones con los LEDs, haciendo que vayan cambiando con el tiempo, tanto de color como cual está encendido. Para ello se va a experimentar con el uso de los bucles for, explicados anteriormente, y la función delay(), que permite esperar un tiempo determinado indicado en milisegundos. Para ello se emplea el código “MiDispositivoMIDI_V3_Rev_A3C_Exercise2.ino”.

Código | MiDispositivoMIDI_V3_Rev_A3C_Exercise2.ino
Descripción | Crear animaciones animaciones con los LEDs, haciendo que los colores y LEDs iluminados varíen con el tiempo.
Objetivos | Entender el uso de bucles for y la función delay(). Confirmar haber entendido el Ejercicio 1

Ejercicios | 1. Modificar el bucle for, para verificar que se ha entendido su
funcionamiento. ¿Qué pasaría si se cambia i<16 | por i<20?
2. Modificar el valor del delay, viendo cómo afecta a la animación final.

La siguiente parte de código es la que es de interés. Fijémonos en que una parte ya la conocemos del ejercicio anterior.

for (int i = 0; i < 16; i++) {
ledPad[i][0] = 0;
ledPad[i][1] = 255;
ledPad[i][2] = 0;

delay(500);
updateLEDs();
}

Lo que hace el bucle for, es repetir lo que hay dentro del código mientras que el valor de la i sea menor que 16. Además, cada vez que se ejecuta lo que hay dentro del for, se suma a la i una unidad. Justo eso es lo que simboliza i++, coge el valor de la i y súmale uno. Por lo tanto esta sección de código se ejecutará 16 veces, y la i tomará valores desde 0 a 15.

Teniendo claro lo anterior, nos damos cuenta que lo que se hace con “ledPad” es exactamente a lo que hacíamos en el ejercicio 1, con la salvedad que en vez de iluminar un LED fijo, se ilumina el LED i. Como la i varía entre 0 y 15, vamos a iluminar primero el primero, después el segundo, y así hasta el 15 y último. Entre cada uno, se espera 500 milisegundos, que es lo que significa delay(500).

No hay mejor forma de entenderlo que cacharreando. Por lo tanto, os animamos a que cambiéis diferentes valores:
- Cambiar i<16
- Cambiar valor delay()

Para los que vayan más avanzados, se sugiere intentar iluminar los LED al revés (desde el último al primero), hacer animaciones en las que intervengan varios LEDs o probar a dibujar una espiral.

### 4.4.3 Ejercicio 3

A continuación vamos a ver cómo podemos enviar mensajes desde el Arduino al ordenador, y como visualizarlos. Para probarlo, vamos a enviar un mensaje si se pulsa uno de los dos botones localizados a los laterales de MiDispositivoMIDI. Se emplea el código “MiDispositivoMIDI_V3_Rev_A3C_Exercise3.ino”.

Código | MiDispositivoMIDI_V3_Rev_A3C_Exercise3.ino

Descripción | Lectura del estado de dos botones, pulsado o no pulsado. Envío del estado a través del puerto serial al ordenador.
Objetivos | 1. Entender el uso de la estructura if-else. 2. Usar el puerto Serial para comunicar al Arduino con el ordenador 3. Usar la función digitalRead().
Ejercicios | 1. Hacer que cuando el botón no está pulsado también se envíe un mensaje. 2. Algo más complicado. Hacer si que se pulsa el botón, solamente se envíe una vez el mensaje de que ha sido pulsado.

La primera diferencia que vemos con respecto a los códigos anteriores, es que se añaden dos líneas al apartado de setup(). Simplemente se configura los botones de controlador como entrada (INPUT).
pinMode(SW_0_PIN, INPUT);
pinMode(SW_1_PIN, INPUT);

La siguiente parte importante, es en la que se usa la función digitalRead(). Esta función devuelve un 1 si el botón está pulsado y un 0 si no lo está. Como entrada, le tenemos que decir cuál es el pin que queremos leer. En el siguiente código, la primera variable almacenará el estado del primero pulsador, y la segunda el estado del segundo pulsador. uint8_t switch0 = digitalRead(SW_0_PIN);
uint8_t switch1 = digitalRead(SW_1_PIN);

Una vez hemos almacenado el valor, miramos si es igual a uno. En el caso de que sea igual a uno, el botón está pulsado. Si está pulsado, enviamos un mensaje por el puerto Serial. Esto es lo que hace el siguiente fragmento de código. Ver si la variable switch1 vale 1, y si es cierto, envía por el puerto Serial el mensaje “Button 0 is pushed”.
if (switch0 == 1 ){
Serial.println("Button 0 is pushed"); }

Para ver los mensajes que envía el Arduino a nuestro ordenador, basta con hacer click en la lupa ubicada en la barra de herramientas del Sketch de Arduino.

Figura 20. Barra de herramientas de Arduino. Puerto serial.

Verificar que el baudrate sea de 9600 baudios, aunque es la opción que está por defecto. Dicho valor es simplemente a la velocidad que se comunica nuestro Arduino con el ordenador. Valores más altos implicarán una mayor velocidad de comunicación.

### 4.4.4 Ejercicio 4

Para este ejemplo emplearemos el código “MiDispositivoMIDI_V3_Rev_A3C_Exercise4.ino” y un secuenciador o DAW (Digital Audio Workstatio). Un DAW es un programa que permite entre otras cosas, recibir mensajes MIDI, interpretarlos y reproducir sonidos en consecuencia. Algunos de los más típicos son Ableton Live, Cubase, Nuendo, Logic o Reason. En el caso de no disponer de uno de estos programas mencionados, se recomienda alguna alternativa libre de código abierto.

Código | MiDispositivoMIDI_V3_Rev_A3C_Exercise4.ino
Descripción | Experimentar con el envío de mensajes MIDI como noteOn y noteOff, viendo los diferentes parámetros que componen el mensaje. Se requerirá un software en el ordenador que permita interpretar los mensajes (Ableton Live, Logic, Cubase, Reason o similar)
Objetivos | Entender el concepto de canal MIDI, velocidad, y nota. Familiarizarse con el uso de noteOn y noteOff. Ver el efecto que tiene el envío de un mensaje MIDI en un secuenciador.
Ejercicios | 1. Modificar los valores de velocidad 2. Modificar las notas enviadas 3. Crear una melodía sencilla 4. Para los más avanzados, experimentar con la recepción de mensajes MIDI. Ver librería “MIDIUSB.h” y su documentación asociada.

Pero antes de entrar con secuenciadores, vamos a primero entender cómo funciona el código para enviar MIDI. Se va a probar con los mensajes de noteOn y noteOff, que permitirán enviar la pulsación de una nota, con una determinada intensidad. Un mensaje noteOn, tiene 3 parámetros: el canal MIDI, la nota que se quiere enviar y la intensidad. En la siguiente sección de código, se puede ver cómo se envía un mensaje de nota activada por el canal 0, la nota 48 y con una intensidad de 127. Recordar que la intensidad va desde 0 a 127, por lo que 127 es el valor de máxima intensidad.

noteOn(0, 48, 127);
MidiUSB.flush();
delay(500);

Como hemos visto, el fragmento de código anterior envía la nota 48 por el canal 0 y con una intensidad máxima (127). Pero claro, ¿que nota es la 48?. Aquí está la tabla de correspondencias:

Octava | Números
C | C# | D | D# | E | F | F# | G | G# | A | A# | B

-2 | 0 | 1 | 2 | 3 | 4 | 5 | 6 | 7 | 8 | 9 | 10 | 11
-1 | 12 | 13 | 14 | 15 | 16 | 17 | 18 | 19 | 20 | 21 | 22 | 23
0 | 24 | 25 | 26 | 27 | 28 | 29 | 30 | 31 | 32 | 33 | 34 | 35
1 | 36 | 37 | 38 | 39 | 40 | 41 | 42 | 43 | 44 | 45 | 46 | 47
2 | 48 | 49 | 50 | 51 | 52 | 53 | 54 | 55 | 56 | 57 | 58 | 59
3 | 60 | 61 | 62 | 63 | 64 | 65 | 66 | 67 | 68 | 69 | 70 | 71
4 | 72 | 73 | 74 | 75 | 76 | 77 | 78 | 79 | 80 | 81 | 82 | 83
5 | 84 | 85 | 86 | 87 | 88 | 89 | 90 | 91 | 92 | 93 | 94 | 95
6 | 96 | 97 | 98 | 99 | 100 | 101 | 102 | 103 | 104 | 105 | 106 | 107
7 | 108 | 109 | 110 | 111 | 112 | 113 | 114 | 115 | 116 | 117 | 118 | 119
8 | 120 | 121 | 122 | 123 | 124 | 125 | 126 | 127 | - | - | - | -

Como se puede ver, los valores de las notas musicales del mensaje noteOn, tienen también valores comprendidos entre 0 y 127. En la tabla anterior hemos visto la correspondencia con las notas musicales, empleando el cifrado americano. Las correspondencias son las siguientes:

Cifrado americano | Nomenclatura latina
A | LA
B | SI
C | DO
D | RE
E | MI
F | FA
G | SOL

Volvamos al código. Antes hemos visto que el mensaje noteOn permite enviar un mensaje de nota activada. Dicha nota seguirá sonando hasta que se envíe un mensaje de noteOff. En las siguientes líneas se muestra el envío de nota desactivada. Se puede ver como el valor de la intensidad toma el valor de 0 (es decir, sin pulsar). Se está enviando un mensaje de nota desactivada por el canal 0, en la nota 48 (la misma que anteriormente se envió que estaba pulsada) y con la intensidad 0. Un mensaje noteOff siempre tendrá una intensidad de 0.

noteOff(0, 48, 0);
MidiUSB.flush();
delay(500);

Por lo tanto el código del ejemplo envía un mensaje de nota activada, espera 500 ms y envía un mensaje para la misma nota pero diciendo que se ha desactivado.

Como se ha indicado anteriormente, es necesario tener en el ordenador instalado un programa que reciba estos mensajes MIDI, los procese y emita sonidos en consecuencia. Para el caso de Ableton Live, basta con configurar en Live/Preferencias/MIDI lo siguiente:

Figura 21. Configuración de un controlador en Ableton Live.

Si ahora añadimos una pista MIDI con un instrumento virtual cargado, y tenemos conectado a nuestro MiDispositivoMIDI, podremos escuchar como se está continuamente enviando una nota, parando y volviendo a enviar. Para los que no tengáis Ableton, no tengáis secuenciador o no sepáis configurarlo, contactad con nosotros y daremos soporte específico.

### 4.4.5 Ejercicio 5

Código | MiDispositivoMIDI_V3_Rev_A3C_Exercise5.ino
Descripción | Código muy similar al “...Simple”. Es completamente compatible con Ableton. Envía MIDI y gestiona los colores de los LED en función de si el botón está pulsado o no.
Objetivos | Entender por encima el código y realizar modificaciones en la sección del código “This following section can be changed by the user”.
Ejercicios | 1. Cambiar las notas que envía cada botón. 2. Cambiar las intensidades de cada botón. 3. Cambiar los colores de los LED sin pulsar 4. Cambiar los colores de los LED al pulsar

Se deja libertad al usuario para que realice las modificaciones que considere oportunas. Se recomienda modificar sólo la sección de código indicada para ello.

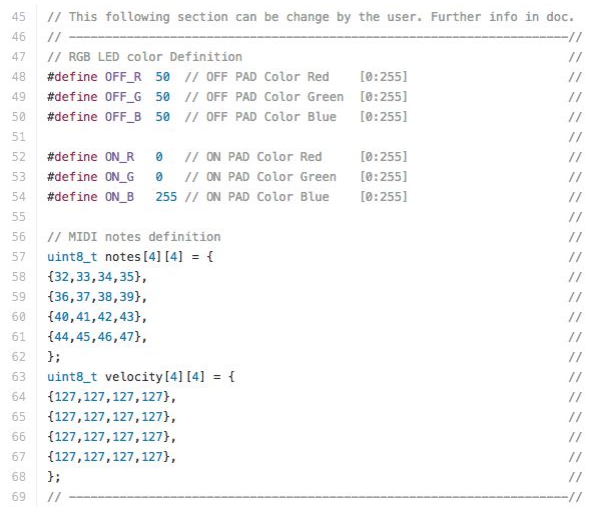
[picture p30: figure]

Figura 22. Sección de código modificable.

# 5. Secuenciadores

## 5.1 Configuración Ableton

El código “...Simple” disponible en nuestro repositorio de GitHub (ver inventario de código) puede ser usado con programas como Ableton Live de manera muy sencilla. Dicho código, es también es el que se encuentra cargado por defecto en el controlador cuando es comprado.
El primer paso es conectar MiDispositivoMIDI y abrir Ableton. Ir a la sección de configuración del programa “Preferencias”. Es necesario hacer una pequeña configuración, como en cualquier controladro comercial.

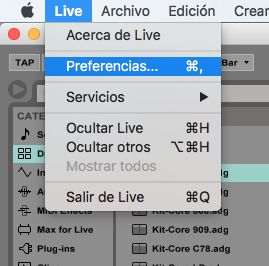
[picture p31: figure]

Figura 23. Configuración en Ableton de un controlador MIDI.

Seleccionar la pestaña “MIDI”.

Figura 24. Pestaña de configuración “MIDI Sync”

Verificar que “Pista” y “Remote” está en “sí” para la entrada del Arduino Leonardo. Una vez realizado, ya puedes hacer música con tu MiDispositivoMIDI.

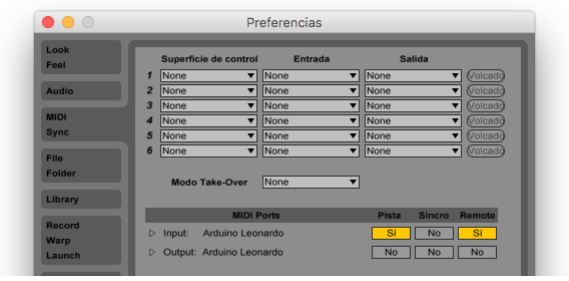
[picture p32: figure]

Figura 25. Configuración de “Pista” y “Remote” para el uso de un controlador.

# 6. Conclusión

## 6.1 Extensión

MiDispositivoMIDI es un controlador de 16 botones dispuestos en una matriz de 4x4 botones con un LED por botón. Sin embargo, permite ser ampliado de manera modular hasta 4 matrices de 4x4, con diferentes configuraciones, 8x8 o 16x4. Notar que para la ampliación, es necesario un MiDispositivoMIDI V3 y 3 MDM_LEDPad. Actualmente no vendemos por separado las placas MDM_LEDPad, pero si estás especialmente interesado, contacta con nosotros en bananutelectronics@gmail.com.

## 6.3 Foro web

Puedes consultar en nuestro foro www.bananutelectronics.com cualquier duda, problema o sugerencias que tengas sobre nuestro controlador. Rogamos que antes de preguntar en el foro, busques si tu problema ya ha sido resuelto.
A los más experimentados programando, les invitamos a que compartan sus códigos con los demás en el foro, para que otros puedan usarlo o colaborar.

## 6.4 FAQ

¿Cómo uso MiDispositivoMIDI?
Nuestro controlador MiDispositivoMIDI es compatible con cualquier secuenciador del mercado (Nuendo, Ableton Live, Logic,...) ya que el funcionamiento es igual al de cualquier otro controlador comercial. Se entrega montado y programado listo para funcionar.

Tengo problemas ¿qué hago?
El controlador se entrega totalmente probado y configurado listo para funcionar. Si tienes alguna duda o problemas, te agradeceríamos que postearas un comentario en nuestro foro (www.bananutelectronics.com). Te contestaremos en la mayor brevedad posible.

No se programar, ¿es MiDispositivoMIDI para mi?
Nuestro controlador esta pensado para gente con o sin conocimientos de programación. Se entrega listo para funcionar y no se tiene porque saber programar para poder usarlo. Si quieres modificar el comportamiento del controlador, también damos códigos listos para ser cargados. Para los que sepan programar o quieran aprender, también se da material (ver “Ejercicios”).

# 7. Inventario de vídeos

Se pueden encontrar en nuestro canal de youtube. (https://www.youtube.com/channel/UCHQbpOPa1lVauoBouRJ16Iw) En ellos encontrarás desde cómo configurar el controlador hasta cómo poder programarlo a tu medida.

INVENTARIO VÍDEOS

Iniciación. Para quién lo quiera conectar y a funcionar.

Presentación: Características del controlador, componentes, disposición de los mismos, desmontaje y montaje.

Demo: Ejemplos con algunas de las posibilidades del controlador. Se hace uso del controlador tal y como llegaría al ser comprado.

Modificaciones. Para quién quiera programar su controlador al gusto.

Instalación: Uso del programa Simple con Ableton. Explicación de su funcionamiento y configuración con secuenciadores. Dicho programa es el que viene por defecto cargado.

(*)Ejercicio 1: Realización del primer ejercicio de la guía paso a paso. El objetivo es introducir como se realiza el control de los LEDs.

(*)Ejercicio 2: Segundo ejercicio de la guía. Introduce la estructura de control for y el uso de la función delay().

(*)Ejercicio 3: Lectura de botones y envío a través del puerto Serial información de pulsado o no pulsado.

(*)Ejercicio 4: Breve explicación del protocolo MIDI y modificaciones sobre el código para entender cómo modificar la nota y velocidad que se envía.

(*)Ejercicio 5: Modificaciones muy sencillas sobre el código por defecto Simple. Se enseña a cambiar los colores y modificar las notas que envía cada botón.

Los vídeos marcados con (*) están pendientes de realizarse. Los tendremos en el mínimo tiempo posible. Los códigos están disponibles en el apartado “Ejercicios”

# 8. Inventario código

Se puede acceder a diferentes códigos para MiDispositivoMIDI en nuestro repositorio de GitHub. (https://github.com/bananutelectronics/MiDispositivoMIDI_A3C) Animamos a que os los descarguéis y probéis en vuestro controlador. También a los más experimentados a hacer forks con nuevas funcionalidades. Para cargar los códigos, deberás descargarte el entorno de desarrollo de Arduino (ver vídeo Instalación). (https://www.youtube.com/channel/UCHQbpOPa1lVauoBouRJ16Iw) Recuerda que no es necesario saber programar para poder usar los códigos, simplemente aprender a cargarlos. Lee la descripción del código y decide cuál crees que le puede ir mejor a tu controlador.

Nombre código | Descripción
MiDispositivoMIDI_V3_Rev_A3C_Simple_V1 | Dicho código se encuentra cargado por defecto en el controlador. Cuando un botón es pulsado, se ilumina el PAD correspondiente y se envía una nota MIDI. Al ser liberado se envía el mensaje de noteOff. Los botones laterales cambian las notas enviadas. Ver vídeo demo. (https://www.youtube.com/channel/UCHQbpOPa1lVauoBouRJ16Iw)
MiDispositivoMIDI_V3_Rev_A3C_ColorTest | Realiza animaciones con los LEDs. No posee funcionalidad MIDI.
MiDispositivoMIDI_V3_Rev_A3B_StepSeq_V1 | Funciona como un step sequencer de 16 notas.
MiDispositivoMIDI_V3_Rev_A3C_Exercise1 | Ejercicio que permite familiarizarse con el manejo de los LED RGB. Se proponen varias modificaciones.
MiDispositivoMIDI_V3_Rev_A3C_Exercise2 | En este ejercicio se enseña a crear animaciones sencillas con los LED. Se introduce el uso del for y la función delay().
MiDispositivoMIDI_V3_Rev_A3C_Exercise3 | Ejercicio en el que se introduce el uso de la función digitalRead() para leer el estado de los pulsadores laterales.
MiDispositivoMIDI_V3_Rev_A3C_Exercise4 | Se explican los fundamentos del MIDI con un sencillo ejemplo.
MiDispositivoMIDI_V3_Rev_A3C_Exercise5 | Ejercicio similar al código “Simple”. Se propone realizar modificaciones sobre el código, cambiando los colores de los botones, las notas e intensidades que se envían. Ver la sección del código

“this section can be changed by the
user”. | Dicho | código | contiene
funcionalidades MIDI y puede ser usado con un secuenciador (Ableton, Logic).

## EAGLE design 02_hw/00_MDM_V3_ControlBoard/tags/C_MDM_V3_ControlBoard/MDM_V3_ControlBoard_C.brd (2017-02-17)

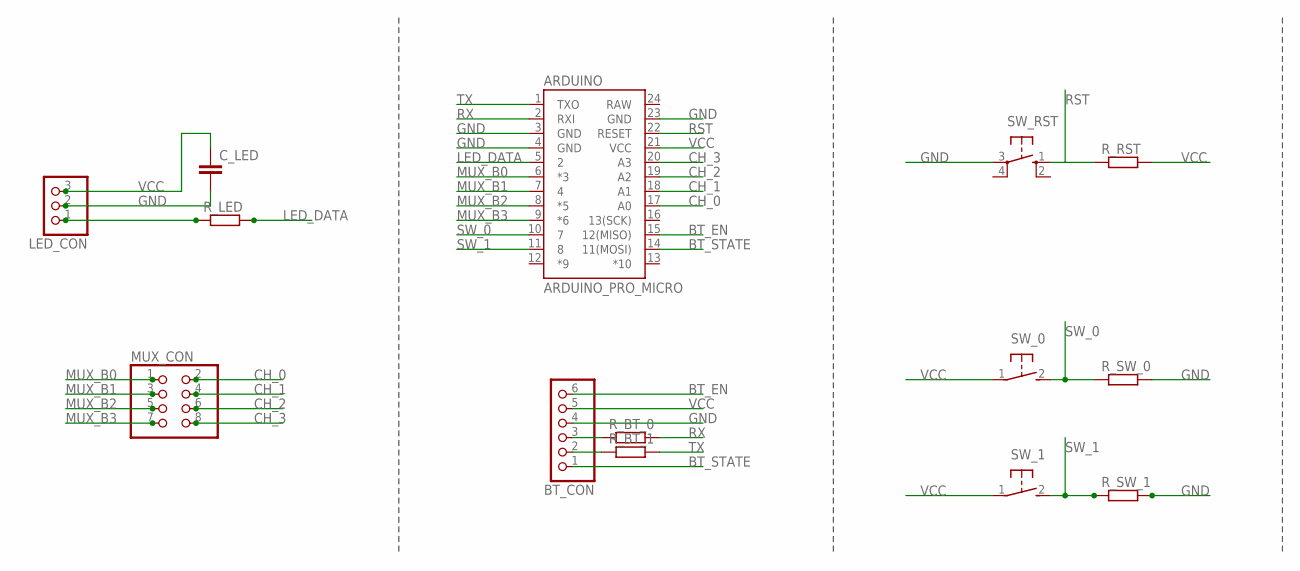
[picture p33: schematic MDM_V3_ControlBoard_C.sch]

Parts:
ARDUINO: ARDUINO_PRO_MICRO
BT_CON: PINHD-1X6; 1X06
C_LED: C-EUC1206K; C1206K
LED_CON: PINHD-1X3; 1X03
MUX_CON: PINHD-2X4; 2X04
R_BT_0, R_BT_1: R-EU_M1206; M1206
R_LED: R-EU_M1206; M1206
R_RST: R-EU_M1206; M1206
R_SW_0, R_SW_1: R-EU_M1206; M1206
SW_0, SW_1: 31-XX; B3F-31XX
SW_RST: 10-XX; B3F-10XX

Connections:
BT_EN: ARDUINO.15 (12(MISO)), BT_CON.6
BT_STATE: ARDUINO.14 (11(MOSI)), BT_CON.1
CH_0: ARDUINO.17 (A0), MUX_CON.2
CH_1: ARDUINO.18 (A1), MUX_CON.4
CH_2: ARDUINO.19 (A2), MUX_CON.6
CH_3: ARDUINO.20 (A3), MUX_CON.8
GND: ARDUINO.3 (GND), ARDUINO.4 (GND), ARDUINO.23 (GND), BT_CON.4, C_LED.2, LED_CON.2, R_SW_0.2, R_SW_1.2, SW_RST.3
LED_DATA: ARDUINO.5 (2), R_LED.2
MUX_B0: ARDUINO.6 (*3), MUX_CON.1
MUX_B1: ARDUINO.7 (4), MUX_CON.3
MUX_B2: ARDUINO.8 (*5), MUX_CON.5
MUX_B3: ARDUINO.9 (*6), MUX_CON.7
unnamed: BT_CON.2, R_BT_1.1
unnamed: BT_CON.3, R_BT_0.1
unnamed: LED_CON.1, R_LED.1
RST: ARDUINO.22 (RESET), R_RST.1, SW_RST.1 (S)
RX: ARDUINO.2 (RXI), R_BT_0.2
SW_0: ARDUINO.10 (7), R_SW_0.1, SW_0.2 (S)
SW_1: ARDUINO.11 (8), R_SW_1.1, SW_1.2 (S)
TX: ARDUINO.1 (TXO), R_BT_1.2
VCC: ARDUINO.21 (VCC), BT_CON.5, C_LED.1, LED_CON.3, R_RST.2, SW_0.1, SW_1.1

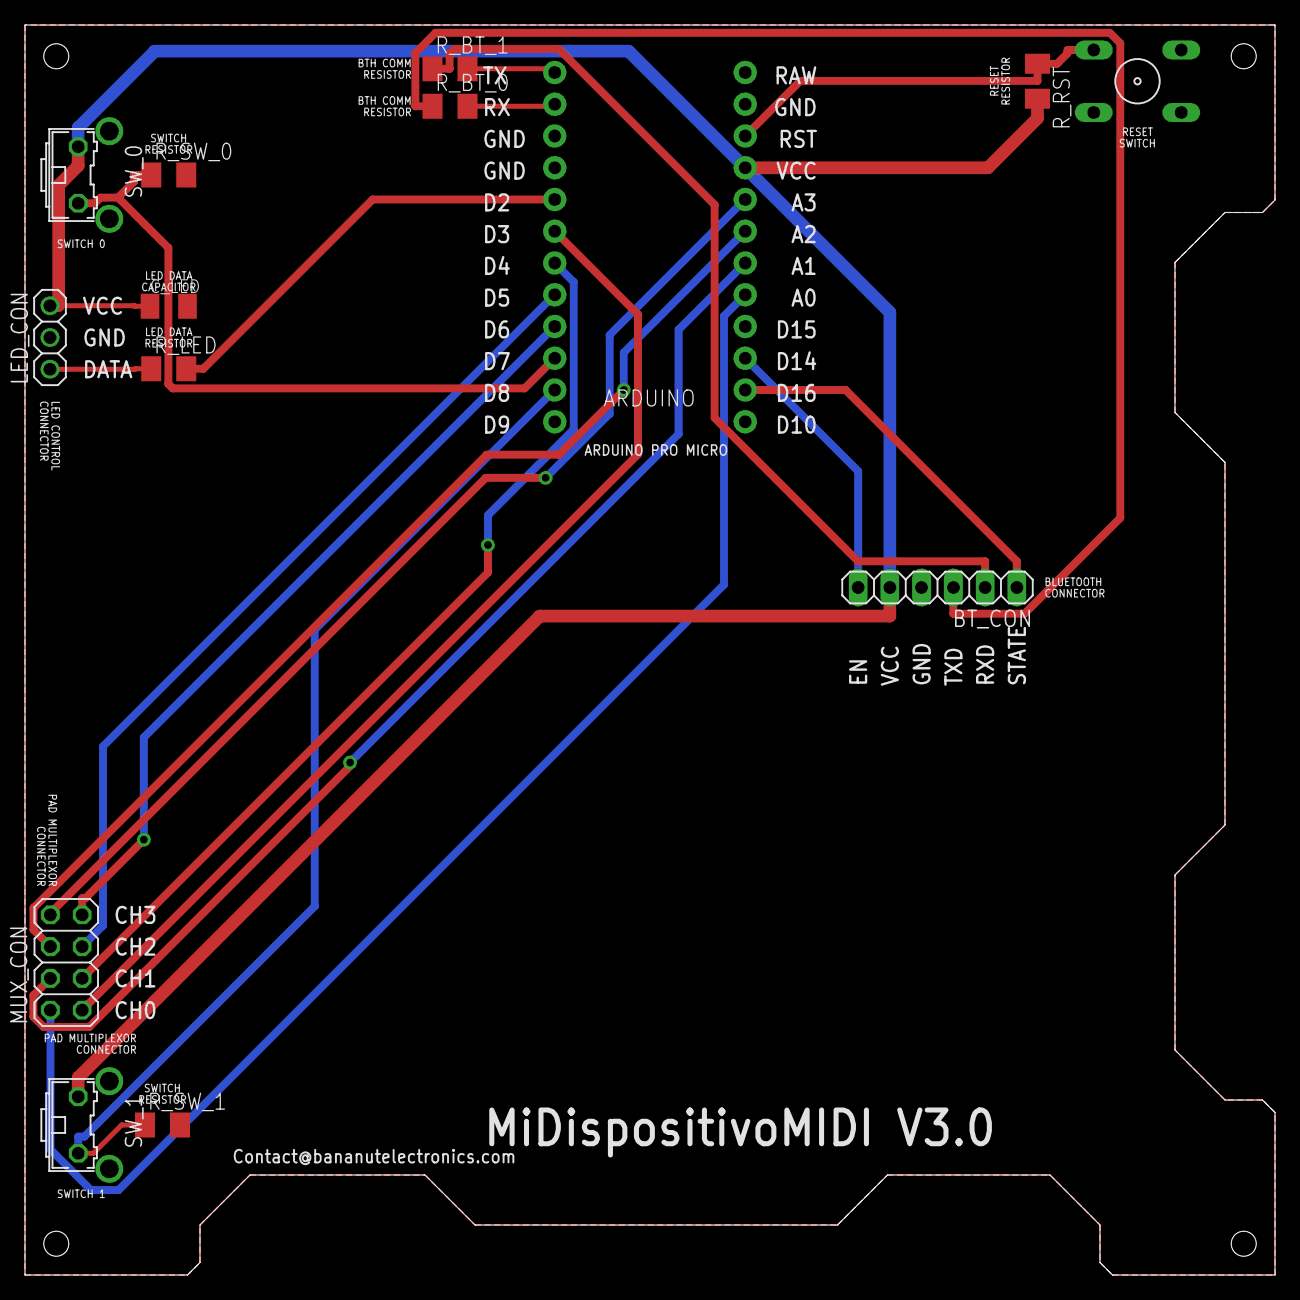
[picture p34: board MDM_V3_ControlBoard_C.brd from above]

Board: 2 copper layers, 100.0 x 100.0 mm, 14 parts (0 on the bottom side), 21 nets.

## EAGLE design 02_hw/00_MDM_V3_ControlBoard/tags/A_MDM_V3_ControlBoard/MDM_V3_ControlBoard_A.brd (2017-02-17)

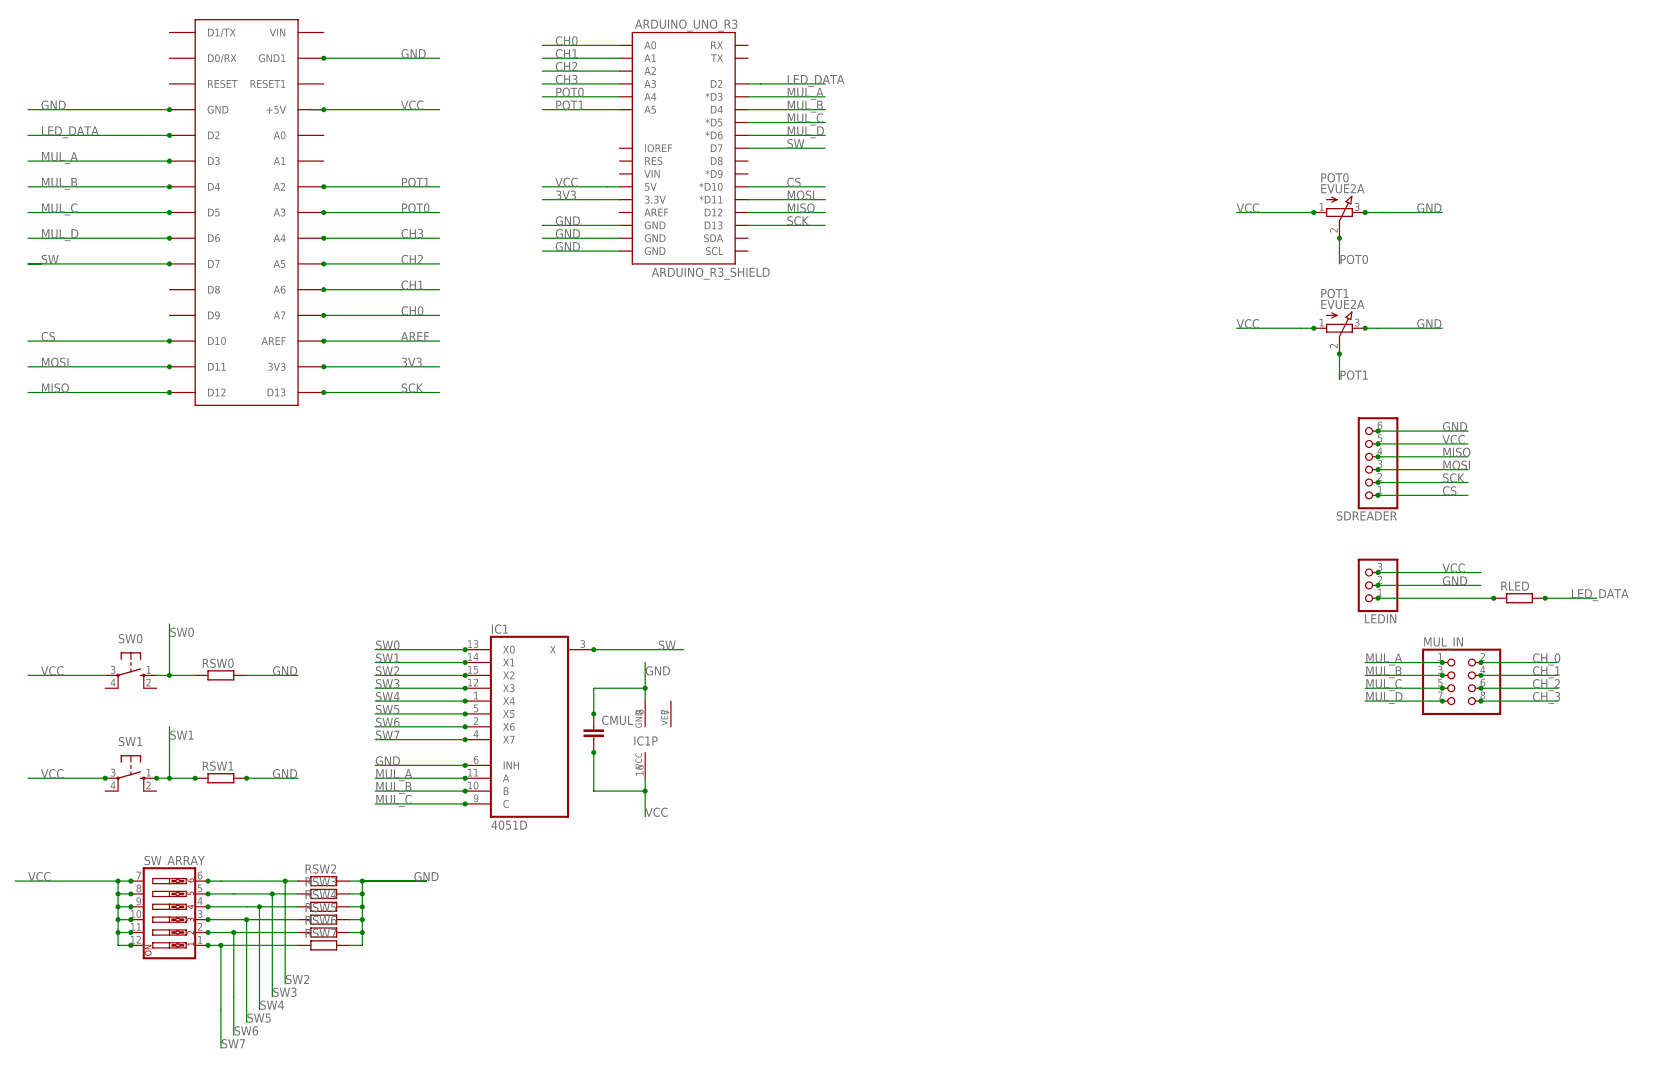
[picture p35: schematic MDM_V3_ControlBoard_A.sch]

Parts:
ARDUINO_NANO: ARDUINONANO; PDIP-32
ARDUINO_UNO_R3: ARDUINO_R3_SHIELD; UNO_R3_SHIELD
CMUL: C-EUC1206; C1206
IC1: 4051D; SO16
LEDIN: PINHD-1X3; 1X03
MUL_IN: PINHD-2X4; 2X04
POT0, POT1: EVUE2A; EVUE
RLED: R-EU_M1206; M1206
RSW0, RSW1, RSW2, RSW3, RSW4, RSW5, RSW6, RSW7: R-EU_M1206; M1206
SDREADER: PINHD-1X6; 1X06
SW0, SW1: 10-XX; B3F-10XX
SW_ARRAY: SW_DIP-6; EDG-06

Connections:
3V3: ARDUINO_NANO.3V3, ARDUINO_UNO_R3.3.3V
AREF: ARDUINO_NANO.AREF
CH0: ARDUINO_NANO.A7, ARDUINO_UNO_R3.A0
CH1: ARDUINO_NANO.A6, ARDUINO_UNO_R3.A1
CH2: ARDUINO_NANO.A5, ARDUINO_UNO_R3.A2
CH3: ARDUINO_NANO.A4, ARDUINO_UNO_R3.A3
CH_0: MUL_IN.2
CH_1: MUL_IN.4
CH_2: MUL_IN.6
CH_3: MUL_IN.8
CS: ARDUINO_NANO.D10, ARDUINO_UNO_R3.D10 (*D10), SDREADER.1
GND: ARDUINO_NANO.GND, ARDUINO_NANO.GND1, ARDUINO_UNO_R3.GND@0 (GND), ARDUINO_UNO_R3.GND@1 (GND), ARDUINO_UNO_R3.GND@2 (GND), CMUL.1, IC1.6 (INH), IC1.8 (GND), LEDIN.2, POT0.3 (E), POT1.3 (E), RSW0.2, RSW1.2, RSW2.2, RSW3.2, RSW4.2, RSW5.2, RSW6.2, RSW7.2, SDREADER.6
LED_DATA: ARDUINO_NANO.D2, ARDUINO_UNO_R3.D2, RLED.2
MISO: ARDUINO_NANO.D12, ARDUINO_UNO_R3.D12, SDREADER.4
MOSI: ARDUINO_NANO.D11, ARDUINO_UNO_R3.D11 (*D11), SDREADER.3
MUL_A: ARDUINO_NANO.D3, ARDUINO_UNO_R3.D3 (*D3), IC1.11 (A), MUL_IN.1
MUL_B: ARDUINO_NANO.D4, ARDUINO_UNO_R3.D4, IC1.10 (B), MUL_IN.3
MUL_C: ARDUINO_NANO.D5, ARDUINO_UNO_R3.D5 (*D5), IC1.9 (C), MUL_IN.5
MUL_D: ARDUINO_NANO.D6, ARDUINO_UNO_R3.D6 (*D6), MUL_IN.7
unnamed: LEDIN.1, RLED.1
POT0: ARDUINO_NANO.A3, ARDUINO_UNO_R3.A4, POT0.2 (S)
POT1: ARDUINO_NANO.A2, ARDUINO_UNO_R3.A5, POT1.2 (S)
SCK: ARDUINO_NANO.D13, ARDUINO_UNO_R3.D13, SDREADER.2
SW: ARDUINO_NANO.D7, ARDUINO_UNO_R3.D7, IC1.3 (X)
SW0: IC1.13 (X0), RSW0.1, SW0.1 (S)
SW1: IC1.14 (X1), RSW1.1, SW1.1 (S)
SW2: IC1.15 (X2), RSW2.1, SW_ARRAY.6
SW3: IC1.12 (X3), RSW3.1, SW_ARRAY.5
SW4: IC1.1 (X4), RSW4.1, SW_ARRAY.4
SW5: IC1.5 (X5), RSW5.1, SW_ARRAY.3
SW6: IC1.2 (X6), RSW6.1, SW_ARRAY.2
SW7: IC1.4 (X7), RSW7.1, SW_ARRAY.1
VCC: ARDUINO_NANO.+5V, ARDUINO_UNO_R3.5V, CMUL.2, IC1.16 (VCC), LEDIN.3, POT0.1 (A), POT1.1 (A), SDREADER.5, SW0.3, SW1.3, SW_ARRAY.7, SW_ARRAY.8, SW_ARRAY.9, SW_ARRAY.10, SW_ARRAY.11, SW_ARRAY.12
VEE: IC1.7 (VEE)

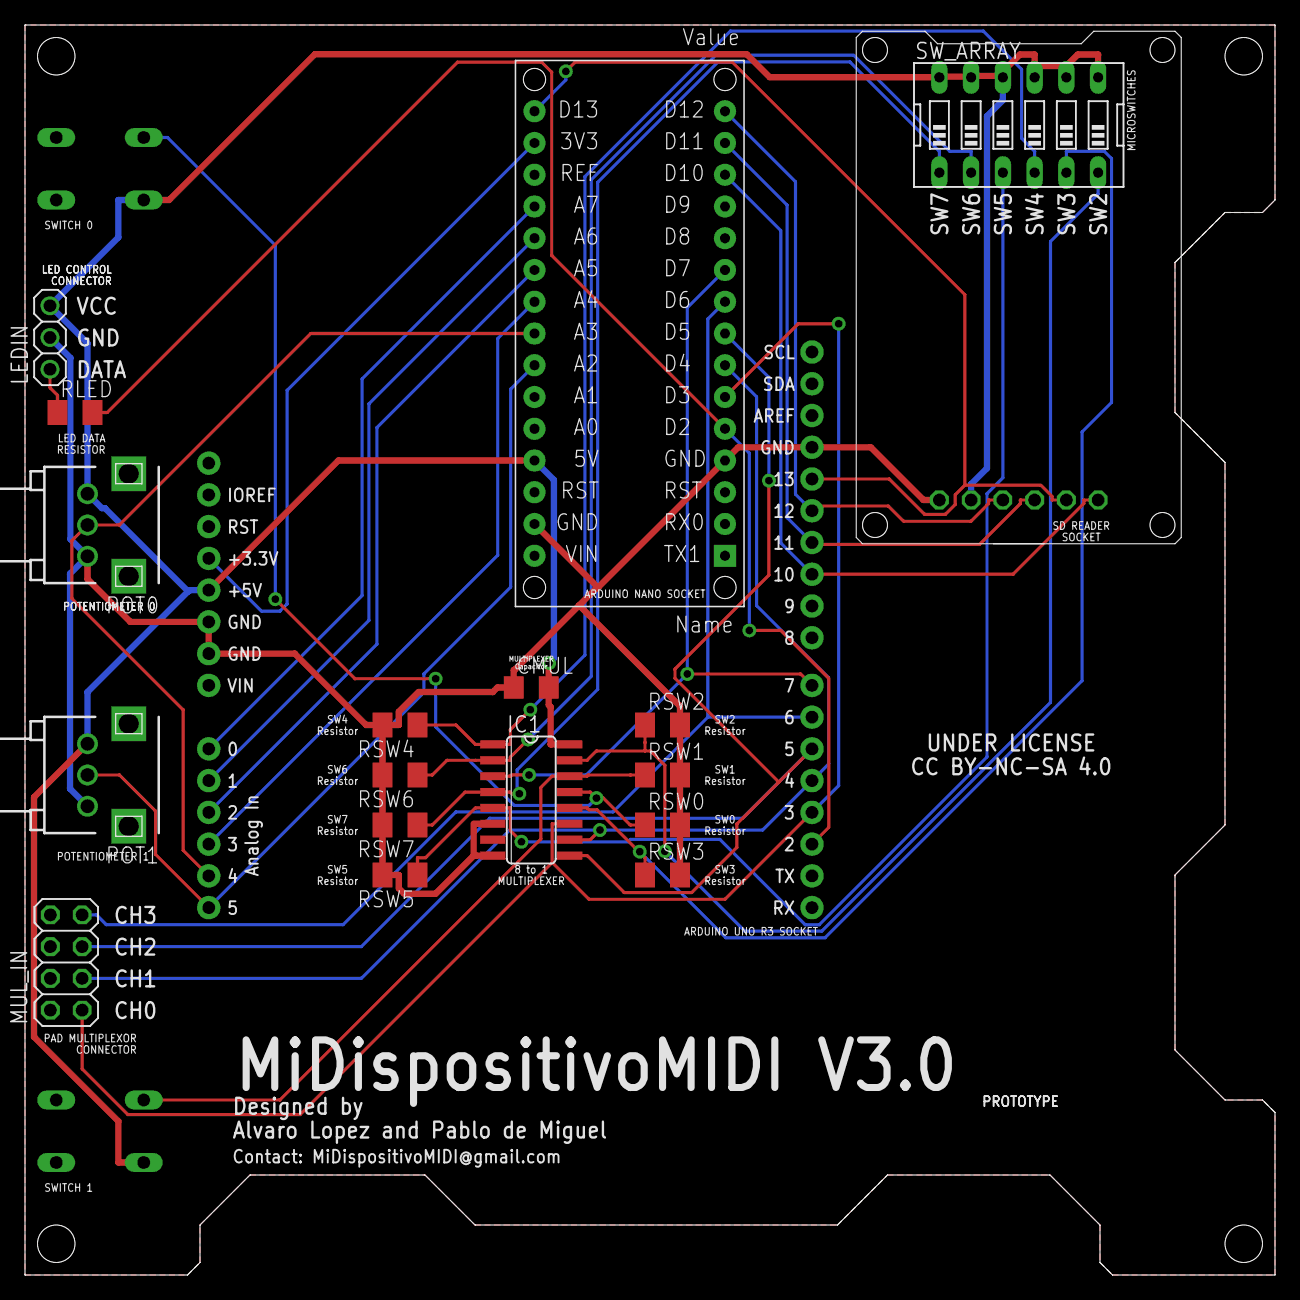
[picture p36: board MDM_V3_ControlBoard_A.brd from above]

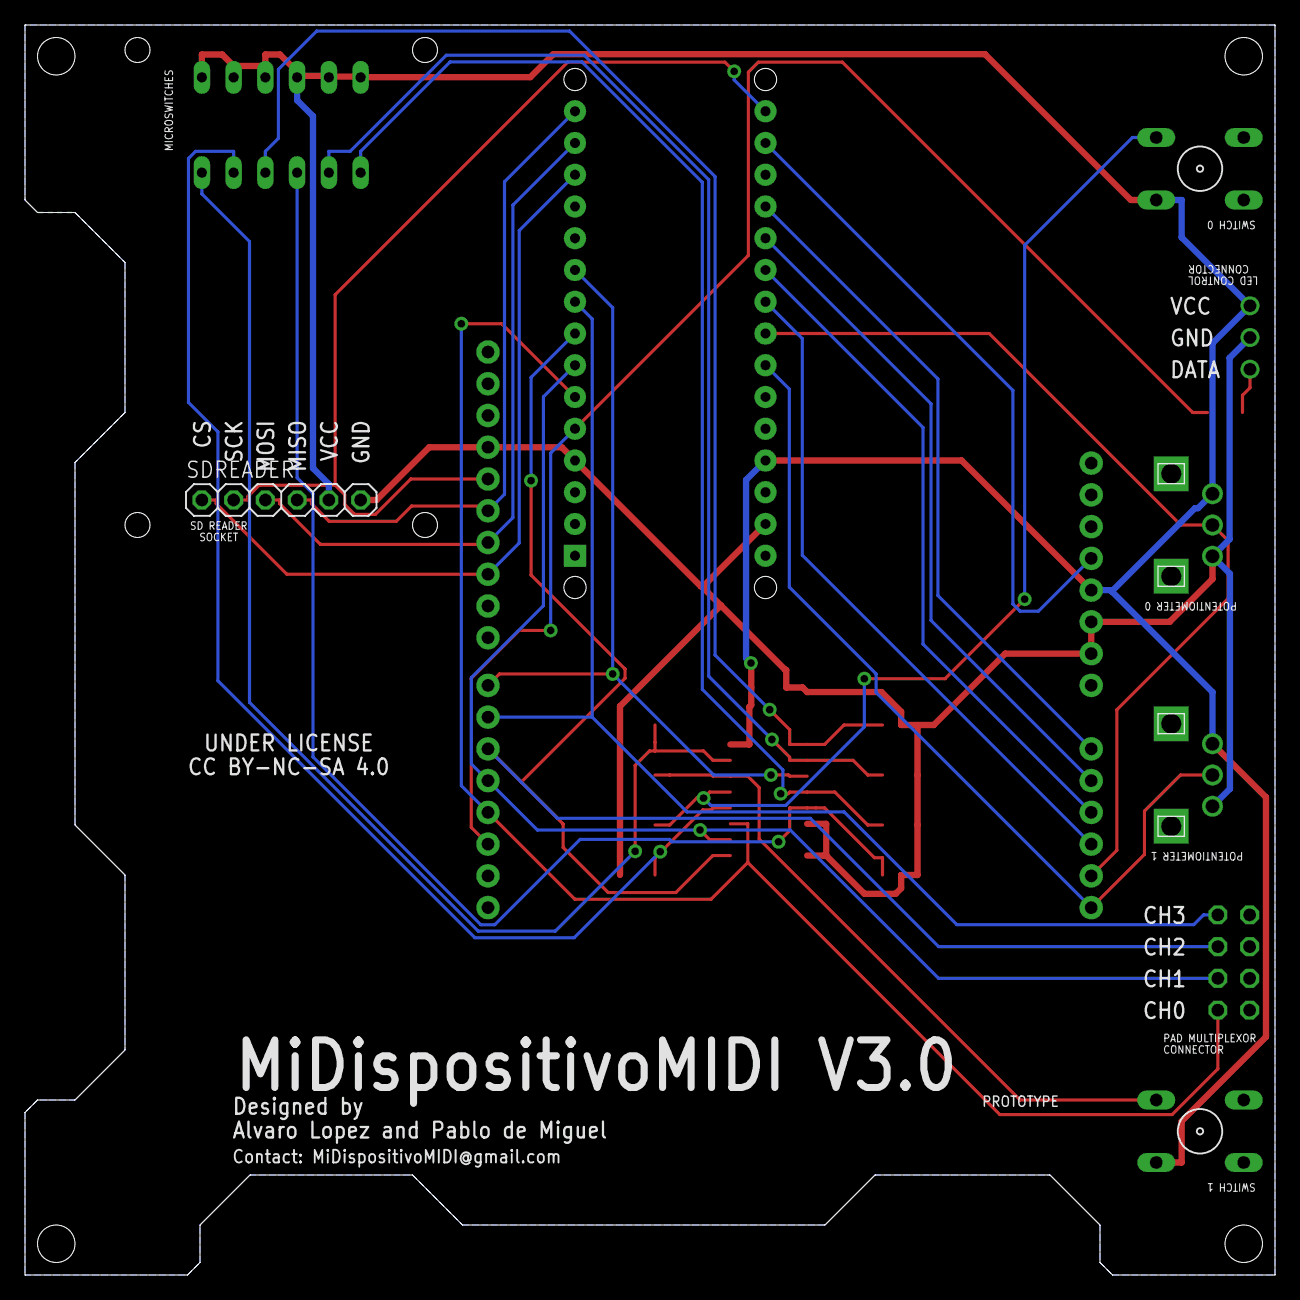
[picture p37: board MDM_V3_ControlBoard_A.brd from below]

Board: 2 copper layers, 100.0 x 100.0 mm, 21 parts (3 on the bottom side), 28 nets.

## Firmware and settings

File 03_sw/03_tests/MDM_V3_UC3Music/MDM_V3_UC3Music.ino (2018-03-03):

// Library Import
#include <Adafruit_NeoPixel.h>
#include <MIDIUSB.h>

// MIDI MSSG VALUES

// First Byte
#define NOTE_ON     0x90
#define NOTE_OFF    0x80
#define CONTROL     0xB0

// Second Byte
#define MODULATION  1
#define VOLUME      7

// SECOND BYTE NOTE VALUES ------------------------------------------------------------------------------------------------------------------------------------
// OCTAVE 00              || OCTAVE 01               || OCTAVE 02               || OCTAVE 03              || OCTAVE 04               || OCTAVE 05
//-------------------------------------------------------------------------------------------------------------------------------------------------------------
const byte NOTE_C0  =  0  ;const byte NOTE_C1  = 12  ;const byte NOTE_C2  = 24  ;const byte NOTE_C3  = 36  ;const byte NOTE_C4  = 48  ;const byte NOTE_C5  = 60;
const byte NOTE_C0s =  1  ;const byte NOTE_C1s = 13  ;const byte NOTE_C2s = 25  ;const byte NOTE_C3s = 37  ;const byte NOTE_C4s = 49  ;const byte NOTE_C5s = 61;
const byte NOTE_D0  =  2  ;const byte NOTE_D1  = 14  ;const byte NOTE_D2  = 26  ;const byte NOTE_D3  = 38  ;const byte NOTE_D4  = 50  ;const byte NOTE_D5  = 62;
const byte NOTE_D0s =  3  ;const byte NOTE_D1s = 15  ;const byte NOTE_D2s = 27  ;const byte NOTE_D3s = 39  ;const byte NOTE_D4s = 51  ;const byte NOTE_D5s = 63;
const byte NOTE_E0  =  4  ;const byte NOTE_E1  = 16  ;const byte NOTE_E2  = 28  ;const byte NOTE_E3  = 40  ;const byte NOTE_E4  = 52  ;const byte NOTE_E5  = 64;
const byte NOTE_F0  =  5  ;const byte NOTE_F1  = 17  ;const byte NOTE_F2  = 29  ;const byte NOTE_F3  = 41  ;const byte NOTE_F4  = 53  ;const byte NOTE_F5  = 65;
const byte NOTE_F0s =  6  ;const byte NOTE_F1s = 18  ;const byte NOTE_F2s = 30  ;const byte NOTE_F3s = 42  ;const byte NOTE_F4s = 54  ;const byte NOTE_F5s = 66;
const byte NOTE_G0  =  7  ;const byte NOTE_G1  = 19  ;const byte NOTE_G2  = 31  ;const byte NOTE_G3  = 43  ;const byte NOTE_G4  = 55  ;const byte NOTE_G5  = 67;
const byte NOTE_G0s =  8  ;const byte NOTE_G1s = 20  ;const byte NOTE_G2s = 32  ;const byte NOTE_G3s = 44  ;const byte NOTE_G4s = 56  ;const byte NOTE_G5s = 68;
const byte NOTE_A0  =  9  ;const byte NOTE_A1  = 21  ;const byte NOTE_A2  = 33  ;const byte NOTE_A3  = 45  ;const byte NOTE_A4  = 57  ;const byte NOTE_A5  = 69;
const byte NOTE_A0s = 10  ;const byte NOTE_A1s = 22  ;const byte NOTE_A2s = 34  ;const byte NOTE_A3s = 46  ;const byte NOTE_A4s = 58  ;const byte NOTE_A5s = 70;
const byte NOTE_B0  = 11  ;const byte NOTE_B1  = 23  ;const byte NOTE_B2  = 35  ;const byte NOTE_B3  = 47  ;const byte NOTE_B4  = 59  ;const byte NOTE_B5  = 71;

// SECOND BYTE NOTE VALUES -----------------------------------------------------------------------------------------------------------
// OCTAVE 06              || OCTAVE 07               || OCTAVE 08               || OCTAVE 09               || OCTAVE 10           
//------------------------------------------------------------------------------------------------------------------------------------
const byte NOTE_C6  = 72  ;const byte NOTE_C7  = 84  ;const byte NOTE_C8  = 96  ;const byte NOTE_C9  =108  ;const byte NOTE_C10  =120;
const byte NOTE_C6s = 73  ;const byte NOTE_C7s = 85  ;const byte NOTE_C8s = 97  ;const byte NOTE_C9s =109  ;const byte NOTE_C10s =121;
const byte NOTE_D6  = 74  ;const byte NOTE_D7  = 86  ;const byte NOTE_D8  = 98  ;const byte NOTE_D9  =110  ;const byte NOTE_D10  =122;
const byte NOTE_D6s = 75  ;const byte NOTE_D7s = 87  ;const byte NOTE_D8s = 99  ;const byte NOTE_D9s =111  ;const byte NOTE_D10s =123;
const byte NOTE_E6  = 76  ;const byte NOTE_E7  = 88  ;const byte NOTE_E8  =100  ;const byte NOTE_E9  =112  ;const byte NOTE_E10  =124;
const byte NOTE_F6  = 77  ;const byte NOTE_F7  = 89  ;const byte NOTE_F8  =101  ;const byte NOTE_F9  =113  ;const byte NOTE_F10  =125;
const byte NOTE_F6s = 78  ;const byte NOTE_F7s = 90  ;const byte NOTE_F8s =102  ;const byte NOTE_F9s =114  ;const byte NOTE_F10s =126;
const byte NOTE_G6  = 79  ;const byte NOTE_G7  = 91  ;const byte NOTE_G8  =103  ;const byte NOTE_G9  =115;
const byte NOTE_G6s = 80  ;const byte NOTE_G7s = 92  ;const byte NOTE_G8s =104  ;const byte NOTE_G9s =116;
const byte NOTE_A6  = 81  ;const byte NOTE_A7  = 93  ;const byte NOTE_A8  =105  ;const byte NOTE_A9  =117;
const byte NOTE_A6s = 82  ;const byte NOTE_A7s = 94  ;const byte NOTE_A8s =106  ;const byte NOTE_A9s =118;
const byte NOTE_B6  = 83  ;const byte NOTE_B7  = 95  ;const byte NOTE_B8  =107  ;const byte NOTE_B9  =119;

// PIN DEFINITION
// Digital Pin Definitions
#define LED    2
#define SW_0   7
#define SW_1   8

// Analog Pin Definitions
#define CH_0   0
#define CH_1   1
#define CH_2   2
#define CH_3   3

#define MUX_A  3
#define MUX_B  4
#define MUX_C  5
#define MUX_D  6

// CONSTANT DEFINITION
#define SW_Q   16 // Number of SW_Pads
#define SC_Q   8 // Number of Scales
#define ON     1  // ON Value
#define OFF    0  // OFF Value

//MACROS Templates
#define PREDEF 0
#define DRUM 11

// USER PROGRAMMING INTERFACE --------------------------------------------------------------------------------
// -----------------------------------------------------------------------------------------------------------

// MIDI Channel Colours
// COLOR RED [0:255]         || COLOR GREEN [0:255]          || COLOR BLUE [0:255]          || Comments
//------------------------------------------------------------------------------------------------------------

//Color de la Base
const byte BCK_R_OFF  = 100   ;const byte BCK_G_OFF  = 100    ;const byte BCK_B_OFF  = 100; // MIDI Channel 15  //Blanco Tenue

//Color de las teclas encendidas 
const byte CH_00_R_ON =   0   ;const byte CH_00_G_ON =   0    ;const byte CH_00_B_ON = 255; // MIDI Channel 00  Azul
const byte CH_01_R_ON =   0   ;const byte CH_01_G_ON = 144    ;const byte CH_01_B_ON = 255; // MIDI Channel 01  Azulito
const byte CH_02_R_ON =  64   ;const byte CH_02_G_ON = 192    ;const byte CH_02_B_ON = 208; // MIDI Channel 02  Azul/Blanco
const byte CH_03_R_ON = 112   ;const byte CH_03_G_ON = 240    ;const byte CH_03_B_ON = 160; // MIDI Channel 03  Celeste
const byte CH_04_R_ON =  00   ;const byte CH_04_G_ON = 255    ;const byte CH_04_B_ON = 130; // MIDI Channel 04  Turquesa
const byte CH_05_R_ON =   0   ;const byte CH_05_G_ON = 255    ;const byte CH_05_B_ON =   0; // MIDI Channel 05  Verde
const byte CH_06_R_ON = 100   ;const byte CH_06_G_ON = 255    ;const byte CH_06_B_ON =   0; // MIDI Channel 06  Lima
const byte CH_07_R_ON = 255   ;const byte CH_07_G_ON = 255    ;const byte CH_07_B_ON =   0; // MIDI Channel 07  Amarillo
const byte CH_08_R_ON = 255   ;const byte CH_08_G_ON = 128    ;const byte CH_08_B_ON =   0; // MIDI Channel 08  Naranjarillo
const byte CH_09_R_ON = 240   ;const byte CH_09_G_ON = 112    ;const byte CH_09_B_ON =  16; // MIDI Channel 09  Naranja
const byte CH_10_R_ON = 150   ;const byte CH_10_G_ON =   0    ;const byte CH_10_B_ON = 255; // MIDI Channel 10  Moradito
const byte CH_11_R_ON = 255   ;const byte CH_11_G_ON = 255    ;const byte CH_11_B_ON = 255; // MIDI Channel 11  Blanco
const byte CH_12_R_ON = 208   ;const byte CH_12_G_ON =  80    ;const byte CH_12_B_ON =  64; // MIDI Channel 12  Rosita
const byte CH_13_R_ON = 255   ;const byte CH_13_G_ON =   0    ;const byte CH_13_B_ON = 150; // MIDI Channel 13  Fucia
const byte CH_14_R_ON = 255   ;const byte CH_14_G_ON =   0    ;const byte CH_14_B_ON =  50; // MIDI Channel 14  Rojosa
const byte CH_15_R_ON = 255   ;const byte CH_15_G_ON =   0    ;const byte CH_15_B_ON =   0; // MIDI Channel 15  Rojo

// SCALE Color Canvas
// COLOR RED [0:255]          || COLOR GREEN [0:255]          || COLOR BLUE [0:255]         || Comments
//------------------------------------------------------------------------------------------------------------
const byte SC_INIT_R  =   0   ;const byte SC_INIT_G  =   0    ;const byte SC_INIT_B  =  50; // INIT from COLOR
const byte SC_END_R   =   0   ;const byte SC_END_G   = 255    ;const byte SC_END_B   = 255; // END to COLOR
const byte SC_ON_R    = 255   ;const byte SC_ON_G    = 255    ;const byte SC_ON_B    = 255; // ON Scale

// OCTAVE Color Canvas
// COLOR RED [0:255]          || COLOR GREEN [0:255]          || COLOR BLUE [0:255]         || Comments
//------------------------------------------------------------------------------------------------------------
const byte OC_INIT_R  =  50   ;const byte OC_INIT_G  =   0    ;const byte OC_INIT_B  =  50; // INIT from COLORº
const byte OC_END_R   =   0   ;const byte OC_END_G   = 255    ;const byte OC_END_B   = 255; // END to COLOR
const byte OC_ON_R    = 255   ;const byte OC_ON_G    = 255    ;const byte OC_ON_B    = 255; // ON Octave

// DEFAULT CONTROL VALUES
int SW_Octave       = 3;   // Starting OCTAVE Value
int SW_Scale        = 0;   // Starting SCALE Value
int SW_MIDIChannel  = 1;   // Starting MIDI_CHANNEL Value
int MDM_MODE        = 0;   // Starting MDM_MODE Value (0 is Notes, 1 is Channel Selection, 2 is Scale/Octave Selection)
int ledEvent        = 1;   // Starting ledEvent Flag

const int PAD_THR   = 500; // SW Push Detection Threshold
const int VELOCITY  = 127; // Default MIDI Note Velocity

bool   SW_CTRL[SW_Q]       = {OFF, OFF, OFF, OFF, OFF, OFF, OFF, OFF, OFF, OFF, OFF, OFF, OFF, OFF, OFF, OFF};
byte   CH_LED[(SW_Q+1)][3] = {{ BCK_R_OFF,  BCK_G_OFF,  BCK_B_OFF},
                              {CH_00_R_ON, CH_00_G_ON, CH_00_B_ON},
                              {CH_01_R_ON, CH_01_G_ON, CH_01_B_ON},
                              {CH_02_R_ON, CH_02_G_ON, CH_02_B_ON},
                              {CH_03_R_ON, CH_03_G_ON, CH_03_B_ON},
                              {CH_04_R_ON, CH_04_G_ON, CH_04_B_ON},
                              {CH_05_R_ON, CH_05_G_ON, CH_05_B_ON},
                              {CH_06_R_ON, CH_06_G_ON, CH_06_B_ON},
                              {CH_07_R_ON, CH_07_G_ON, CH_07_B_ON},
                              {CH_08_R_ON, CH_08_G_ON, CH_08_B_ON},
                              {CH_09_R_ON, CH_09_G_ON, CH_09_B_ON},
                              {CH_10_R_ON, CH_10_G_ON, CH_10_B_ON},
                              {CH_11_R_ON, CH_11_G_ON, CH_11_B_ON}, 
                              {CH_12_R_ON, CH_12_G_ON, CH_12_B_ON},
                              {CH_13_R_ON, CH_13_G_ON, CH_13_B_ON},
                              {CH_14_R_ON, CH_14_G_ON, CH_14_B_ON},
                              {CH_15_R_ON, CH_15_G_ON, CH_15_B_ON}};

byte SW_NOTE[SC_Q][SW_Q] = {{NOTE_C0,  NOTE_D0,   NOTE_E0,   NOTE_F0,   NOTE_G0,   NOTE_A0,   NOTE_B0,  NOTE_C1,  NOTE_D1,   NOTE_E1,   NOTE_F1,   NOTE_G1,   NOTE_A1,   NOTE_B1,  NOTE_C2,  NOTE_D2},   // Escala Mayor  I-II-III-IV-V-VI-VII
                            {NOTE_C1,  NOTE_D1,   NOTE_E1,   NOTE_F1,   NOTE_G1,   NOTE_A1,   NOTE_B1,  NOTE_C2,  NOTE_D2,   NOTE_E2,   NOTE_F2,   NOTE_G2,   NOTE_A2,   NOTE_B2,  NOTE_C3,  NOTE_D3},   // Escala Mayor  I-II-III-IV-V-VI-VII
                            {NOTE_C2,  NOTE_D2,   NOTE_E2,   NOTE_F2,   NOTE_G2,   NOTE_A2,   NOTE_B2,  NOTE_C3,  NOTE_D3,   NOTE_E3,   NOTE_F3,   NOTE_G3,   NOTE_A3,   NOTE_B3,  NOTE_C4,  NOTE_D4},   // Escala Mayor  I-II-III-IV-V-VI-VII
                            {NOTE_C0,  NOTE_D0,   NOTE_E0,   NOTE_F0,   NOTE_G0s,  NOTE_A0,   NOTE_B0,  NOTE_C1,  NOTE_D1,   NOTE_E1,   NOTE_F1,   NOTE_G1s,   NOTE_A1,   NOTE_B1,  NOTE_C2,  NOTE_D2},  // Escala Mayor 5 aumentada  I-II-III-IV-V#-VI-VII
                            {NOTE_C1,  NOTE_D1,   NOTE_E1,   NOTE_F1,   NOTE_G1s,  NOTE_A1,   NOTE_B1,  NOTE_C2,  NOTE_D2,   NOTE_E2,   NOTE_F2,   NOTE_G2,   NOTE_A2,   NOTE_B2,  NOTE_C3,  NOTE_D3},   // Escala Mayor  I-II-III-IV-V-VI-VII
                            {NOTE_C0,  NOTE_D0,   NOTE_E0,   NOTE_G0,   NOTE_A0,   NOTE_C1,   NOTE_D1,  NOTE_E1,  NOTE_G1,   NOTE_A1,   NOTE_C2,   NOTE_D2,   NOTE_E2,   NOTE_G2,  NOTE_A2,  NOTE_C3},   // Pentatonica Mayor  I-II-III-IV-V-VI-VII
                            {NOTE_C0,  NOTE_D0,   NOTE_E0,   NOTE_F0,   NOTE_G0,   NOTE_A0,   NOTE_B0,  NOTE_C1,  NOTE_D1,   NOTE_E1,   NOTE_F1,   NOTE_G1,   NOTE_A2,   NOTE_B2,  NOTE_C2,  NOTE_D2},   // Pentatonica Mayor  I-II-III-IV-V-VI-VII
                            {NOTE_C0,  NOTE_G0,   NOTE_D1,   NOTE_E1,   NOTE_G1,   NOTE_A1,   NOTE_F1,  NOTE_C2,  NOTE_B1,   NOTE_C2,   NOTE_D2,   NOTE_E2,   NOTE_C1,   NOTE_F1,  NOTE_G1,  NOTE_D1}};  // JUMP

int muxSel[4] = {MUX_D, MUX_C, MUX_B, MUX_A}; // MUX Selector Pins
int templateSel = 0; //Selection of templates (0 == predefined)

Adafruit_NeoPixel ledPadStripe = Adafruit_NeoPixel(SW_Q, LED, NEO_RGB + NEO_KHZ800);


void setup() {
  // Baudrate Set
  Serial.begin(115200); 
  // LED Stripe Initialization
  ledPadStripe.begin();
  ledPadStripe.show();
  // Set Pin Modes
  pinMode(MUX_A, OUTPUT);
  pinMode(MUX_B, OUTPUT);
  pinMode(MUX_C, OUTPUT);
  pinMode(MUX_D, OUTPUT);
  //            G   R   B   G             R              B
  LED_FADE_INIT(0, 0, 0, CH_LED[0][1], CH_LED[0][0], CH_LED[0][2], 10, 80);
}

//LOOOOOOOOOOOOOOOOOOOOOOOOOOOOOOOOOOOOOOOOOOOOP
void loop() {
  switch(MDM_MODE){
    
    case 1:      // MIDI CHANNEL Mode
      Serial.println("Hey there 1");
      SW_MC_Read();
      SW_MODE_Read();
      break;

    case 2:      // SCALE/OCTAVE Mode
      Serial.println("Hey there 2");
      SW_Scale++;
      delay(300);
      if(SW_Scale>=SC_Q){
        SW_Scale = 0;}
      MDM_MODE = 0;
      //SW_SCOC_Read();
      //SW_MODE_Read();
      //LED_SCOC_Update();
    break;

    default:      // NOTE Mode
      Serial.print("Hey there 0, Scale is ");
      Serial.println(SW_Scale, DEC);
      SW_NOTE_Read();
      SW_MODE_Read();
    break;
  }
}
//FIIIIIIIIIIIIIIIIIIIIIN

void SW_MODE_Read(){
  if(MDM_MODE == 0){           // If in NOTE MODE ('0')
    if(digitalRead(SW_0)){
      MDM_MODE = 1;        // MIDI CHANNEL Mode ('1')
      LED_MC_InitTransition(8, 10);
    }else if (digitalRead(SW_1)){
      MDM_MODE = 2;        // MIDI CHANNEL Mode ('2')
      changeEscale(8, 100);
    }
  }
}


void SW_MC_Read(){
  for (int i = 0; i < SW_Q; i++) {
    SET_MUXGATE(i);
    if (analogRead(CH_0) < PAD_THR) {
      SW_MIDIChannel = (i+1);
      templateSel = i;
      MDM_MODE = 0;             // Return to NOTE MODE ('0')
      LED_MC_EndTransition();
      
    }
  }
}

void changeEscale(int fadeSteps, int fadeDelay){
    for(int i = 0; i< SW_Q; i++){
      ledPadStripe.setPixelColor(i, 100, 50, 100);   // Heavy Stuff
    }
    delay(fadeDelay);
    ledPadStripe.show(); // Update LEDs
    if(templateSel == DRUM){delay(fadeDelay);drum();}
    else{
      for(int i = 0; i< SW_Q; i++){
        ledPadStripe.setPixelColor(i, 100, 100, 100);   // Heavy Stuff
      }
      delay(fadeDelay);
      ledPadStripe.show(); // Update LEDs
    }
}

void LED_MC_InitTransition(int fadeSteps, int fadeDelay){
  //SW_PAD_SCALE control
  for(int h = 0; h < fadeSteps; h++){
    ledPadStripe.setPixelColor(0, ((CH_LED[1][1]/fadeSteps)*h), ((CH_LED[1][0]/fadeSteps)*h), ((CH_LED[1][2]/fadeSteps)*h));   // Heavy Stuff
    delay(fadeDelay);
    ledPadStripe.show(); // Update LEDs 
  }
  for(int h = 0; h < fadeSteps; h++){
    ledPadStripe.setPixelColor(1, ((CH_LED[2][1]/fadeSteps)*h), ((CH_LED[2][0]/fadeSteps)*h), ((CH_LED[2][2]/fadeSteps)*h));   // Heavy Stuff
    ledPadStripe.setPixelColor(4, ((CH_LED[5][1]/fadeSteps)*h), ((CH_LED[5][0]/fadeSteps)*h), ((CH_LED[5][2]/fadeSteps)*h));   // Heavy Stuff
    ledPadStripe.setPixelColor(5, ((CH_LED[6][1]/fadeSteps)*h), ((CH_LED[6][0]/fadeSteps)*h), ((CH_LED[6][2]/fadeSteps)*h));   // Heavy Stuff
    delay(fadeDelay);
    ledPadStripe.show(); // Update LEDs 
  }
  for(int h = 0; h < fadeSteps; h++){
    ledPadStripe.setPixelColor(2, ((CH_LED[3][1]/fadeSteps)*h), ((CH_LED[3][0]/fadeSteps)*h), ((CH_LED[3][2]/fadeSteps)*h));   // Heavy Stuff
    ledPadStripe.setPixelColor(6, ((CH_LED[7][1]/fadeSteps)*h), ((CH_LED[7][0]/fadeSteps)*h), ((CH_LED[7][2]/fadeSteps)*h));   // Heavy Stuff
    ledPadStripe.setPixelColor(10, ((CH_LED[11][1]/fadeSteps)*h), ((CH_LED[11][0]/fadeSteps)*h), ((CH_LED[11][2]/fadeSteps)*h));   // Heavy Stuff
    ledPadStripe.setPixelColor(9, ((CH_LED[10][1]/fadeSteps)*h), ((CH_LED[10][0]/fadeSteps)*h), ((CH_LED[10][2]/fadeSteps)*h));   // Heavy Stuff
    ledPadStripe.setPixelColor(8, ((CH_LED[9][1]/fadeSteps)*h), ((CH_LED[9][0]/fadeSteps)*h), ((CH_LED[9][2]/fadeSteps)*h));   // Heavy Stuff
    delay(fadeDelay);
    ledPadStripe.show(); // Update LEDs 
  }
  for(int h = 0; h < fadeSteps; h++){
    ledPadStripe.setPixelColor( 3, ((CH_LED[ 4][1]/fadeSteps)*h), ((CH_LED[ 4][0]/fadeSteps)*h), ((CH_LED[ 4][2]/fadeSteps)*h));   // Heavy Stuff
    ledPadStripe.setPixelColor( 7, ((CH_LED[ 8][1]/fadeSteps)*h), ((CH_LED[ 8][0]/fadeSteps)*h), ((CH_LED[ 8][2]/fadeSteps)*h));   // Heavy Stuff
    ledPadStripe.setPixelColor(11, ((CH_LED[12][1]/fadeSteps)*h), ((CH_LED[12][0]/fadeSteps)*h), ((CH_LED[12][2]/fadeSteps)*h));   // Heavy Stuff
    ledPadStripe.setPixelColor(12, ((CH_LED[13][1]/fadeSteps)*h), ((CH_LED[13][0]/fadeSteps)*h), ((CH_LED[13][2]/fadeSteps)*h));   // Heavy Stuff
    ledPadStripe.setPixelColor(13, ((CH_LED[14][1]/fadeSteps)*h), ((CH_LED[14][0]/fadeSteps)*h), ((CH_LED[14][2]/fadeSteps)*h));   // Heavy Stuff
    ledPadStripe.setPixelColor(14, ((CH_LED[15][1]/fadeSteps)*h), ((CH_LED[15][0]/fadeSteps)*h), ((CH_LED[15][2]/fadeSteps)*h));   // Heavy Stuff
    ledPadStripe.setPixelColor(15, ((CH_LED[16][1]/fadeSteps)*h), ((CH_LED[16][0]/fadeSteps)*h), ((CH_LED[16][2]/fadeSteps)*h));   // Heavy Stuff
    delay(fadeDelay);
    ledPadStripe.show(); // Update LEDs 
  }
}

void LED_MC_EndTransition(){
  //SW_PAD_SCALE control
  LED_FADE_INIT(CH_LED[0][1], CH_LED[0][0], CH_LED[0][2], CH_LED[SW_MIDIChannel][1], CH_LED[SW_MIDIChannel][0], CH_LED[SW_MIDIChannel][2], 10, 50);
  LED_FADE_INIT(CH_LED[SW_MIDIChannel][1], CH_LED[SW_MIDIChannel][0], CH_LED[SW_MIDIChannel][2], CH_LED[0][1], CH_LED[0][0], CH_LED[0][2], 10, 50);
  if(templateSel == DRUM){drum();};
}

void SW_NOTE_Read(){
  for (int i = 0; i < SW_Q; i++) {
    SET_MUXGATE(i);
    if (analogRead(CH_0) < PAD_THR) {
      if (!SW_CTRL[i]) { // If SW not activated
        SW_CTRL[i] = ON;
        ledPadStripe.setPixelColor(i, CH_LED[SW_MIDIChannel][1], CH_LED[SW_MIDIChannel][0], CH_LED[SW_MIDIChannel][2]);   // Heavy Stuff
        MIDI_TX(SW_MIDIChannel, NOTE_ON,SW_NOTE[SW_Scale][i] + (12*SW_Octave), VELOCITY);   // MIDI USB MSSG
        delay(1);
        ledPadStripe.show(); // Update LEDs
      }
    }else{
      if (SW_CTRL[i]) { // If SW activated
        SW_CTRL[i] = OFF;
        if(templateSel == DRUM){drum();}
        else{ledPadStripe.setPixelColor(i, CH_LED[0][1], CH_LED[0][0], CH_LED[0][2]);};   // Heavy Stuff
        MIDI_TX(SW_MIDIChannel, NOTE_OFF, SW_NOTE[SW_Scale][i] + (12*SW_Octave), 0);        // MIDI USB MSSG
        delay(1);
        ledPadStripe.show(); // Update LEDs
      }
    }
  }
}
//Falla algo... El el orden de los colores real es G R B G R B
void LED_FADE_INIT(int INIT_R, int INIT_G, int INIT_B, int END_R, int END_G, int END_B, int fadeSteps, int fadeDelay){
  bool dir_R, dir_G, dir_B;
  int  step_R, step_G, step_B;
  int  Red, Grn, Blu;
  
  if(INIT_R >= END_R){
    dir_R = 0;
    step_R = ((INIT_R-END_R)/fadeSteps);
  }else{
    dir_R = 1;
    step_R = ((END_R-INIT_R)/fadeSteps);
  };
  
  if(INIT_G >= END_G){dir_G = 0; step_G = ((INIT_G-END_G)/fadeSteps);}else{dir_G = 1; step_G = ((END_G-INIT_G)/fadeSteps);};
  if(INIT_B >= END_B){dir_B = 0; step_R = ((INIT_B-END_B)/fadeSteps);}else{dir_B = 1; step_B = ((END_B-INIT_B)/fadeSteps);};
  for(int h = 0; h <= fadeSteps; h++){
    if(h == fadeSteps){Red = 100; Grn = 100; Blu = 100;}else{
      if(dir_R){Red = (INIT_R + (h* step_R));}else{Red = (INIT_R - (h* step_R));};
      if(dir_G){Grn = (INIT_G + (h* step_G));}else{Grn = (INIT_G - (h* step_G));};
      if(dir_B){Blu = (INIT_B + (h* step_B));}else{Blu = (INIT_B - (h* step_B));};}
    for(int i = 0; i< SW_Q; i++){
      ledPadStripe.setPixelColor(i, Red, Grn, Blu);   // Heavy Stuff
    }
    delay(fadeDelay);
    ledPadStripe.show(); // Update LEDs
  }
}

void SET_MUXGATE(int GATENUM){
  for (int h = 0; h < 4; h++) {
      digitalWrite(muxSel[h], ((GATENUM >> (3 - h)) & 0x01)); //MUX Setup pin for each MUX Pin
  }
  delay(1); // Delay por MUX Setup
}

void MIDI_TX(byte MIDICHANNEL, byte MESSAGE, byte PITCH, byte VELOCITY) {
  //byte status1 = MESSAGE + MIDICHANNEL;
  //Serial.write(MESSAGE + MIDICHANNEL);
  //Serial.write(PITCH);
  //Serial.write(VELOCITY);
  midiEventPacket_t event = {(byte)(MESSAGE >> 4), (byte)(MESSAGE | (MIDICHANNEL)), PITCH, VELOCITY};
  MidiUSB.sendMIDI(event);
  MidiUSB.flush();
}
void drum(){
      for(int i = 0; i< SW_Q; i++){
        if(i==0){ledPadStripe.setPixelColor(i, CH_LED[5][1], CH_LED[5][0], CH_LED[5][2]);};
        if((i==1)||(i==2)){ledPadStripe.setPixelColor(i, CH_LED[2][1], CH_LED[2][0], CH_LED[2][2]);};
        if(i==3){ledPadStripe.setPixelColor(i, CH_LED[3][1], CH_LED[3][0], CH_LED[3][2]);};
        if(i==4){ledPadStripe.setPixelColor(i, CH_LED[6][1], CH_LED[6][0], CH_LED[6][2]);};
        if((i==5)||(i==6)||(i==11)){ledPadStripe.setPixelColor(i, CH_LED[11][1], CH_LED[11][0], CH_LED[11][2]);};
        if(i==7){ledPadStripe.setPixelColor(i, CH_LED[8][1], CH_LED[8][0], CH_LED[8][2]);};
        if(i==8){ledPadStripe.setPixelColor(i, CH_LED[7][1], CH_LED[7][0], CH_LED[7][2]);};
        if((i==9)||(i==10)){ledPadStripe.setPixelColor(i, CH_LED[10][1], CH_LED[10][0], CH_LED[10][2]);};
        if(i==12){ledPadStripe.setPixelColor(i, CH_LED[13][1], CH_LED[13][0], CH_LED[13][2]);};
        if((i==13)||(i==14)){ledPadStripe.setPixelColor(i, CH_LED[16][1], CH_LED[16][0], CH_LED[16][2]);};
        if(i==15){ledPadStripe.setPixelColor(i, CH_LED[15][1], CH_LED[15][0], CH_LED[15][2]);}; 
    }
    delay(1);
    ledPadStripe.show(); // Update LEDs
}

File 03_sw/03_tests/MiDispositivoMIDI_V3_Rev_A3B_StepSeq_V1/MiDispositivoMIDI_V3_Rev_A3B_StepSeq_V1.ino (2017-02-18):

/*
    MiDispositivoMIDI V3 Rev.A1C StepSeq
    This code works for 16 buttons, without any expansion
    It is a step sequencer, that gets via MIDI the existing tempo in Ableton and
    send a note if the button is pressed.
    Tests
*/
// Library Import
#include <Adafruit_NeoPixel.h>
#include <MIDIUSB.h>

// Digital Pin Definition
#define LEDPAD_PIN  2
#define MUX_B0_PIN  3
#define MUX_B1_PIN  4
#define MUX_B2_PIN  5
#define MUX_B3_PIN  6
#define SW_0_PIN    7
#define SW_1_PIN    8

// Analog Pin Definition
#define POT_0_PIN   4
#define POT_1_PIN   5
#define PADCH_0_PIN 0
#define PADCH_1_PIN 1
#define PADCH_2_PIN 2
#define PADCH_3_PIN 3

// Defined values
#define LEDPAD_EXT  1    //Number of LED PAD Extension Boards [1:4]
#define LEDPAD_NUM  16   //LEDs per PAD
#define PAD_THR     500  //PAD Value Threhold for Action
#define MAX_PAGE    4    //Maximum number of pages. Must be multiple of 4.

// Pad y Multiplexers Pins
uint8_t padPin[4] = {3, 2, 1, 0}; // PAD Channel Pins
uint8_t muxPin[4] = {6, 5, 4, 3}; // MUX Selector Pins

// Global Variables
Adafruit_NeoPixel ledPadStripe = Adafruit_NeoPixel(LEDPAD_NUM*LEDPAD_EXT, LEDPAD_PIN, NEO_RGB + NEO_KHZ800);

// Pages and notes
uint8_t lastSW_1    = 0;
uint8_t lastSW_2    = 0;
uint8_t currentPage = 0; // Current page [1:MAX_PAGE]
uint8_t eightNote   = 0;
uint8_t contador    = 0;
uint8_t negra       = 1;

// Leds and buttons
int padRead[16] = {0};                     // PAD Results. Analog value
uint8_t ledPad[16][3][MAX_PAGE] = {{{0}}}; // LED PAD RGB Color Values
uint8_t lastRead[16][MAX_PAGE] = {{0}};    // Last value read. Digital value [0:1]
uint8_t stepStatus[16][MAX_PAGE] = {{0}};  // Status of each note [0:1]

void setup() {
  // Initialize serial port
  Serial.begin(115200);

  // Initialize led strip
  ledPadStripe.begin();
  ledPadStripe.show();
  
  // Set Pin Modes
  pinMode(MUX_B0_PIN, OUTPUT);
  pinMode(MUX_B1_PIN, OUTPUT);
  pinMode(MUX_B2_PIN, OUTPUT);
  pinMode(MUX_B3_PIN, OUTPUT);
  pinMode(SW_0_PIN, INPUT);
  pinMode(SW_1_PIN, INPUT);

  // Generate seed for random numbers (may be unused)
  randomSeed(200);
}

void loop() {
  midiEventPacket_t rx;
  rx = MidiUSB.read();
  if (rx.byte1 == 0xF8) {
    if (contador % 24 == 0) {
      Serial.println(negra);
      negra++;
      timerIsr();
      contador = 0;
      if (negra == 5) {
        negra = 1;
      }
    }
    //Serial.println(contador);
    contador++;
  }
  if (rx.byte1 == 0xFC) {
    contador = 0;
    negra = 1;
  }


  readPADs();
  //execPADs();
  updateLEDs();
  readPage();
}
/*
 * 
 */
void noteOn(byte channel, byte pitch, byte velocity) {
  midiEventPacket_t noteOn = {0x09, 0x90 | channel, pitch, velocity};
  MidiUSB.sendMIDI(noteOn);
}
/*
 * 
 */
void noteOff(byte channel, byte pitch, byte velocity) {
  midiEventPacket_t noteOff = {0x08, 0x80 | channel, pitch, velocity};
  MidiUSB.sendMIDI(noteOff);
}

/* Function void readPADs()
    Reads the PADs through the MUX.
    Reads a number of LEDPAD_EXT Channels starting from 0
*/
void readPADs() {
  for (int i = 0; i < LEDPAD_NUM; i++) { // PAD Button Iterator
    for (int h = 0; h < 4; h++) {
      digitalWrite(muxPin[h], ((i >> (3 - h)) & 0x01)); //MUX SetUp

      delay(1);
    }
    //delay(1); // Time por MUX SetUp
    //delayMicroseconds(1);
    for (int j = 0; j < LEDPAD_EXT; j++) { // PAD Channel Iterator
      padRead[i] = analogRead(padPin[j]); //Assign Reads to PAD matrix

      //Metido mio aparte de pablo
      if (padRead[i] < PAD_THR) { //Si esta pulsado
        if (lastRead[i][currentPage] == 0) { //Si no se ha enviado ya

          stepStatus[i][currentPage] = !(stepStatus[i][currentPage]);
          //Serial.println(stepStatus[j][i][currentPage]);
          if (stepStatus[i][currentPage] == 1) {
            ledPad[i][0][currentPage] = 255;
            ledPad[i][1][currentPage] = 0;
            ledPad[i][2][currentPage] = 0;
          } else {
            ledPad[i][0][currentPage] = 0;
            ledPad[i][1][currentPage] = 0;
            ledPad[i][2][currentPage] = 0;
          }
          lastRead[i][currentPage] = 1;
          padRead[i] = 0;
          MidiUSB.flush();
        }
      } else { //Al soltar
        if (lastRead[i][currentPage] == 1) {
          lastRead[i][currentPage] = 0;
        }
      }
    }
  }
}

/* Funtion void execPADs()
    Read the PAD matrix and executes actions
*/
// //unused by now
// void execPADs(){
//   for(int i=0; i<LEDPAD_NUM; i++){ // PAD Button Iterator
//      for(int j=0; j<LEDPAD_EXT; j++){ // PAD Channel Iterator
//        if(padRead[j][i] < PAD_THR){
//          //Serial.print("\nPAD CH: ");
//          //Serial.print(j);
//          //Serial.print(" BUTTON PRESSED: ");
//          //Serial.print(i);
//          //noteOn(0, 48, 64);   // Channel 0, middle C, normal velocity
//          //MidiUSB.flush();
//          // Actions should be here
//          ledPad[j][i][1] = 255; // Set Pad LED BLUE
//          padRead[j][i] = 700; // Clean Sticky Reads
//        }else{
//          ledPad[j][i][1] = 0; // Set PAD LED OFF
//          //padRead[j][i] = 0;
//        }
//      }
//  }
// }

/* Function updateLEDPADs()
    Updates the LED PAD values
*/

void updateLEDs() {
  for (int i = 0; i < LEDPAD_NUM; i++) { // PAD Button Iterator
    for (int j = 0; j < LEDPAD_EXT; j++) { // PAD Channel Iterator
      ledPadStripe.setPixelColor((i + (j * LEDPAD_NUM)), ledPad[i][0][currentPage], ledPad[i][1][currentPage], ledPad[i][2][currentPage]); // Heavy Stuff
      //ledPadStripe.setPixelColor((i*(j+1)),ledPad[j][i][0],ledPad[j][i][1],ledPad[j][i][2]); // Heavy Stuff
    }
  }
  ledPadStripe.show(); // Update LEDs
}


void readPage() {
  uint8_t readSW_1 = digitalRead(SW_0_PIN);
  uint8_t readSW_2 = digitalRead(SW_1_PIN);
  if ((readSW_1 == HIGH) && (readSW_1 != lastSW_1)) {
    if (currentPage < (MAX_PAGE - 1)) {
      currentPage++;
    }
  }
  if ((readSW_2 == HIGH) && (readSW_2 != lastSW_2)) {
    if (currentPage > 0) {
      currentPage--;
    }
  }
  lastSW_1 = readSW_1;
  lastSW_2 = readSW_2;
}
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

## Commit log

2018-03-03 Uploading code. Main code is from Bananut's unreleased fw. Features added by Bananut: color selection by palette, more control by constants, reorganiced stuff... Upgrades by UC3Music: working scale c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
2018-03-03 New Colors, Drums Teamplate and Solved Bugs
    With this version of the code some "bugs" are solved, we have more colors and if we select the white template (in the color selection) a drum template is showing in order to see the mapping better...
    Also, when you change the scale a blue light will blink in order "to see" the change of the scale.
    [MDM_V3_UC3Music.ino]

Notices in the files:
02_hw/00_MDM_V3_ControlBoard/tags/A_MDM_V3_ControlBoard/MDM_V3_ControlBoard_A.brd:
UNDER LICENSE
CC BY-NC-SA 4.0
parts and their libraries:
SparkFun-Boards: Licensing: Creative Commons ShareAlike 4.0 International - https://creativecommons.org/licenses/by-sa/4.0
